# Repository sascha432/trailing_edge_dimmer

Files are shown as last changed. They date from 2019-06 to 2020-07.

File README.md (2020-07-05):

# Trailing Edge MOSFET Dimmer

Firmware for a trailing edge MOSFET dimmer.

* 14bit / 16666 different dimming levels
* Up to 8 different channels
* Store last levels in EEPROM and restore during startup
* EEPROM wear level protection
* Serial protocol to control the dimmer
* I2C or UART interface
* Over temperature protection using an external NTC or the internal ATmega temperature sensor
* Highly configurable to match any hardware

[I2C/UART protocol](https://github.com/sascha432/trailing_edge_dimmer/blob/aabc243a570f12f377fd4b94965764b3ff974f6c/docs/protocol.md)

[Change Log v2.1.4](https://github.com/sascha432/trailing_edge_dimmer/blob/aabc243a570f12f377fd4b94965764b3ff974f6c/CHANGELOG.md)

[Release](https://github.com/sascha432/trailing_edge_dimmer/releases/tag/2.1.4)

## Master Branch

The current master is work in progress and should not be used for any production dimmer.

* Breaking I2C protocol updates
* Cubic interpolation to adjust the brightness curve per channel
* Mains frequency detection between 45 and 65 Hz
* Linear correction removed
* Improved and more precise timings
* Reduced code size by 5-7Kb

[I2C/UART protocol](docs/PROTOCOL.md)

[Change Log v3.0.0](CHANGELOG.md)

## GUI tool for configuration

I created a GUI tool to calibrate, configure and monitor the dimmer via serial port, TCP or web sockets.

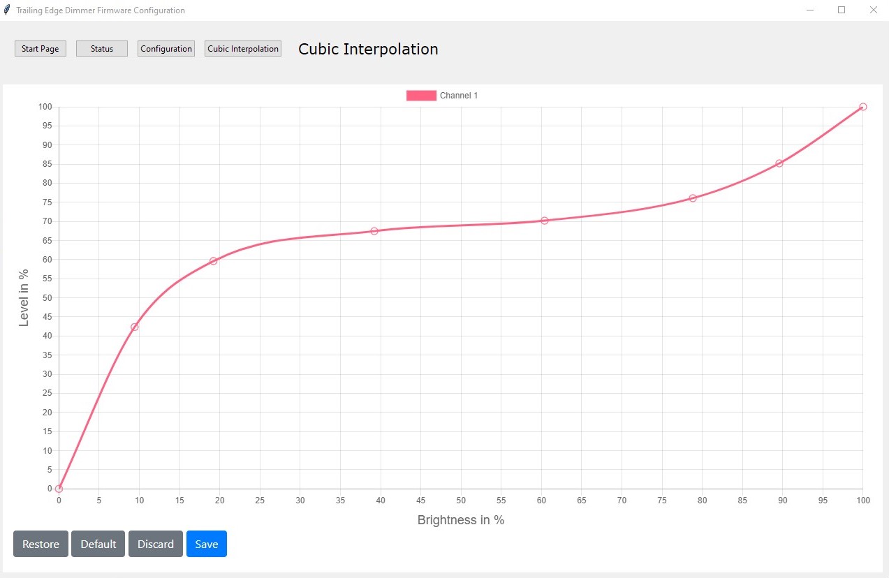
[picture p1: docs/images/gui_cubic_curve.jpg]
GUI tool edit cubic interpolation curve


### Multiple channels

When having multple channels, using a single port reduces any delay when turning channels on. Multiple ports add a slight delay to each channel associated with the port (62.5ns), while version 2 had a delay of 2µs per channel, which added up to 16µs  when having 8 active channels.

Channels that share a port turn on at the same time

* yellow = PORTD
* pink = PORTB
* blue = PORTC

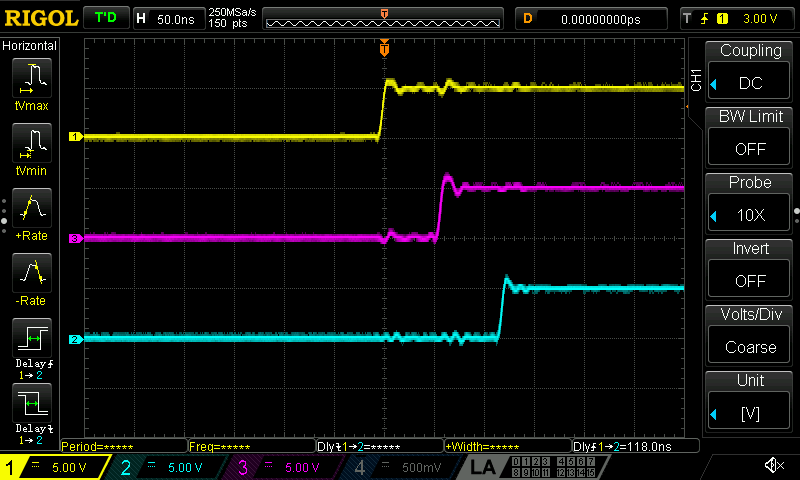
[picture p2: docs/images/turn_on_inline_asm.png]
Version 3


Version 2 or without inline assembler

* yellow = channel#0
* pink = channel#1
* blue = channel#7

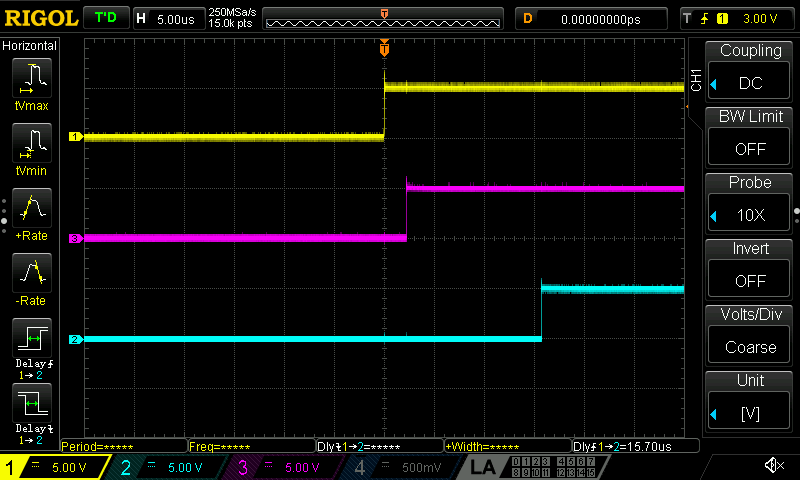
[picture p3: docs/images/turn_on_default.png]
Version 2


## New and improved in-wall dimmer STL files

I have improved and updated the housing for the in-wall dimmer and added print instructions.

* Switches can be mounted on a PCB attached to the plate
* Space for 2 optional LEDs
* Invisible hole for reset switch
* Space for a 20mm fuse holder
* Labels for wires

[3D model in-wall version 1.1](stl/housing/v1.1)

[Instructions](stl/housing/v1.1/README.md)

## New plugin version for 1 Channel Dimmer

Check section [3D models](#3D-models-released) for a plugin housing.

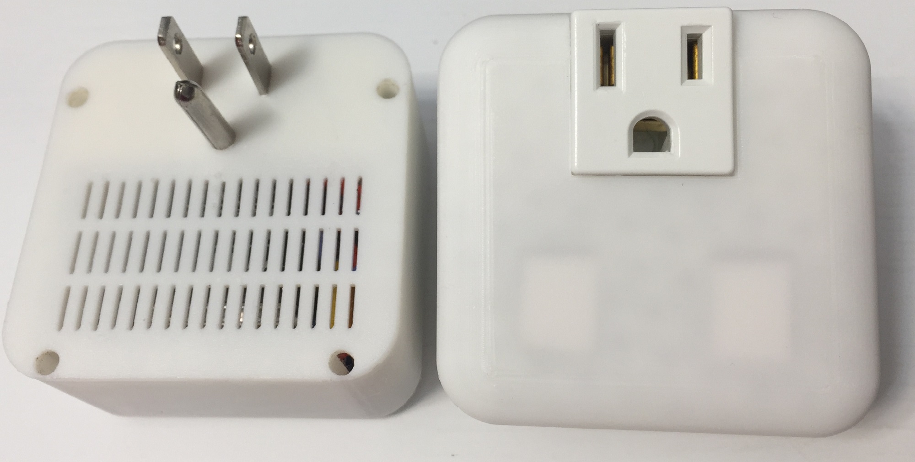
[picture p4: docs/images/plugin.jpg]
Plugin Dimmer


## Updated 4 Channel Dimmer with Power Monitoring

Non isolated version with an offline primary side buck regulator (LNK306), reduced standby consumption of 0.45W compared to 0.58W of the 1 Channel dimmer. Up to 500W with heatsink.

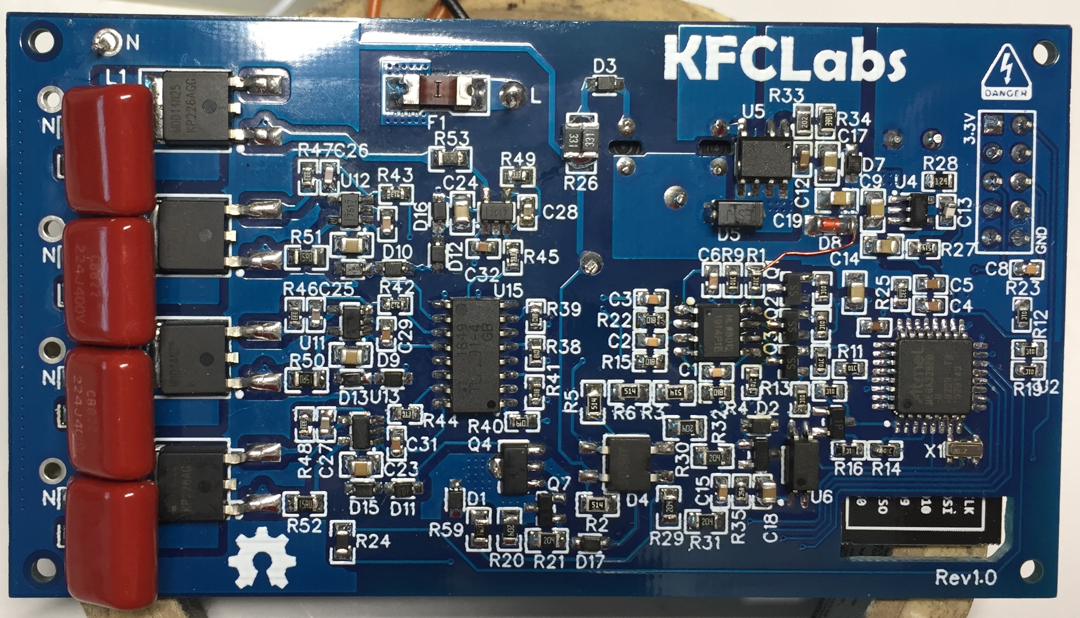
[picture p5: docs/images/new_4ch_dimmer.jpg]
4 Channel Dimmer


[4 Channel Dimmer Schematics and PCB TO-252-2](https://easyeda.com/sascha23095123423/iot-4-channel-dimmer-with-pm)

[4 Channel Dimmer Schematics and PCB TO-220](https://easyeda.com/sascha23095123423/iot-4-channel-dimmer-with-pm_copy)

## Power Monitoring

I've finished testing the new power monitoring feature based on HLW8012 and compatible chips.
The new design uses the Hi-link 3.3V/1A power supply and the MP150, an offline primary side buck regulator, for the non-isolated 5V rail. The regular dimmer got an update as well and 4 MOSFETs can be installed to increase the maximum power up to 200/400W.

[1 Channel Dimmer with Power Monitor](https://easyeda.com/sascha23095123423/iot_1ch_dimmer_copy_copy_copy)

[1 Channel Dimmer with 4 MOSFETs](https://easyeda.com/sascha23095123423/iot_1ch_dimmer_copy_copy_copy_copy)

[New WiFi control board](https://easyeda.com/sascha23095123423/esp12e_iot_module_copy)

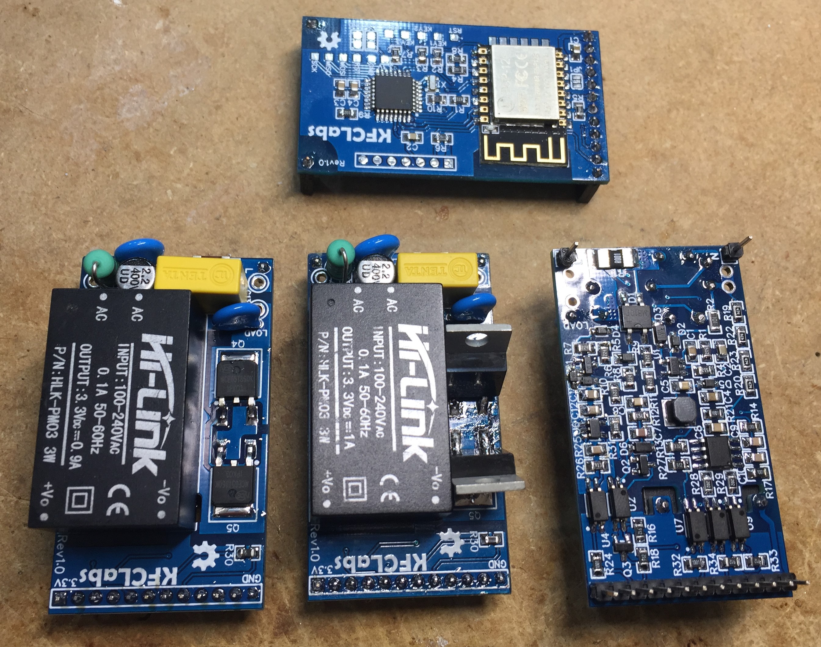
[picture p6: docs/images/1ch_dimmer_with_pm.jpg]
New PCBs


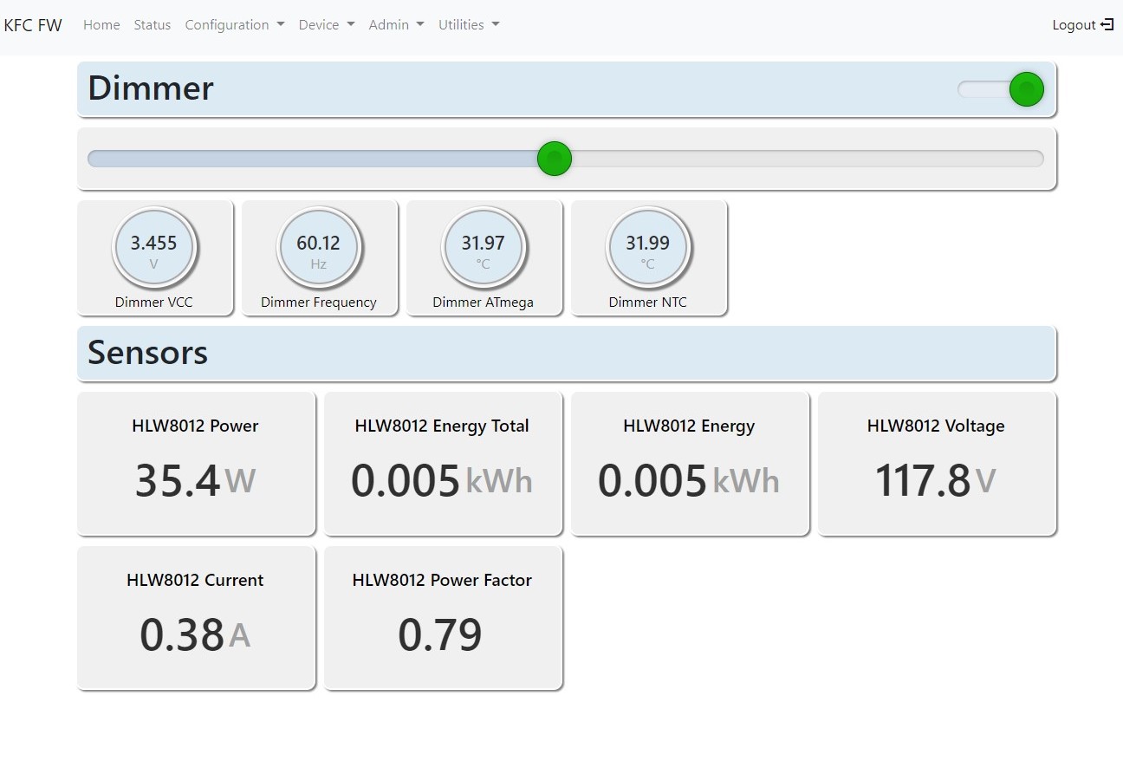
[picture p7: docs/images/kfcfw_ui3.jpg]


## WiFi Firmware update

The recent version of the KFC firmware supports programming the ATmega over the STK500v1 protocol directly from the ESP8266. I am using the Arduino bootloader for the ATmega328P mini PRO board@8MHz (ATmegaBOOT_168_atmega328_pro_8MHz.hex)

[KFC Firmware @ Github](https://github.com/sascha432/esp8266-kfc-fw)

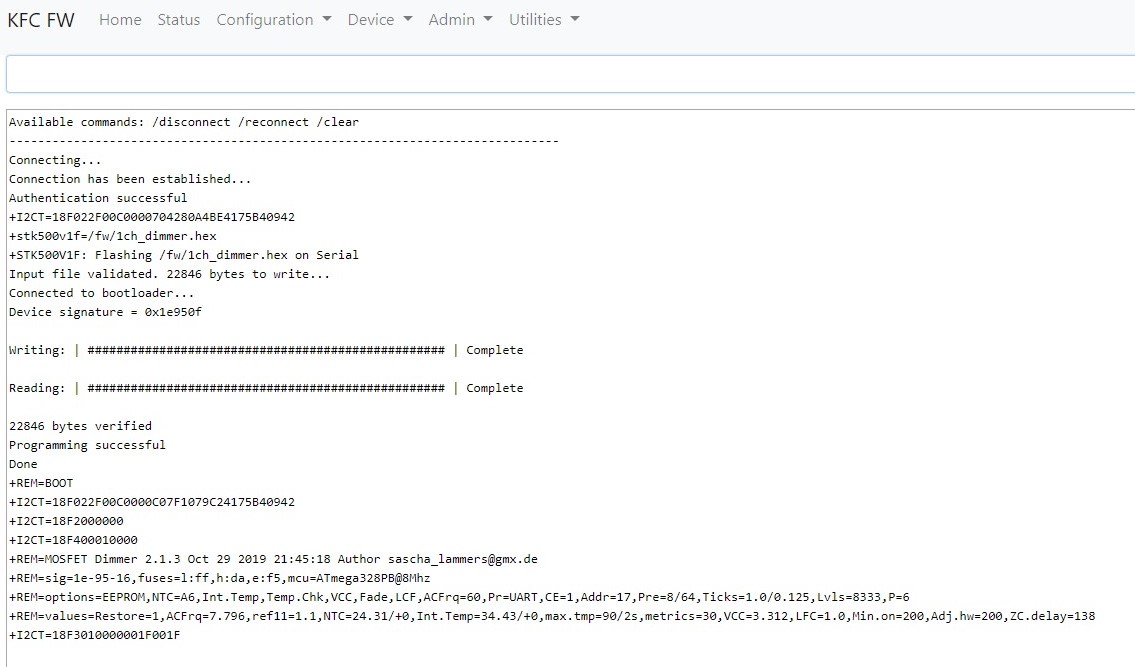
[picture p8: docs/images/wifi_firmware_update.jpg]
WiFi Firmware Update


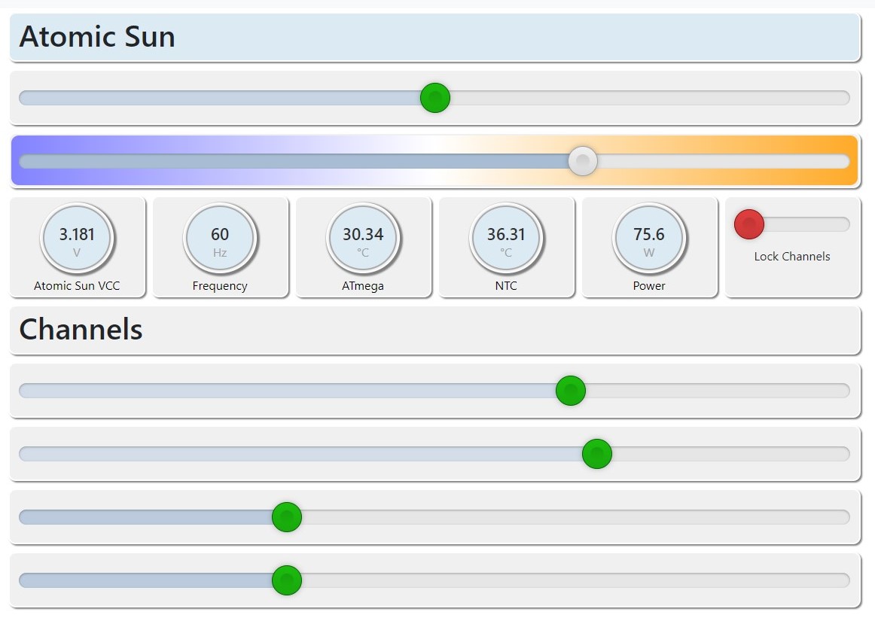
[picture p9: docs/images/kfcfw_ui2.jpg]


## Zero crossing detection update

I've improved the zero crossing detection by adding a RC filter, which improves the signal but still has a 0.5% error rate compared to 2.2% before.
Software filtering reduces the error rate to 0.001% even without the RC filter.

Test environment: 4x10W LED + 60W incandescent bulb, 50% dimmed, random 1000-2500V transients 5-20µs several times per second on the AC side.

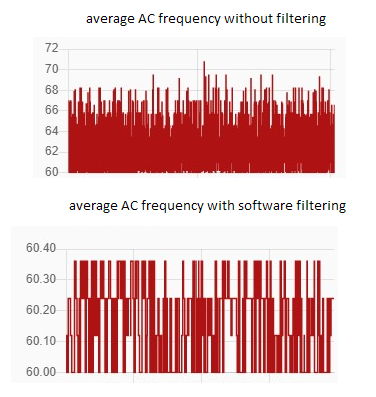
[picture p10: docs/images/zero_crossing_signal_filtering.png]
Comparision of unfiltered and filtered signal


## 3D models released

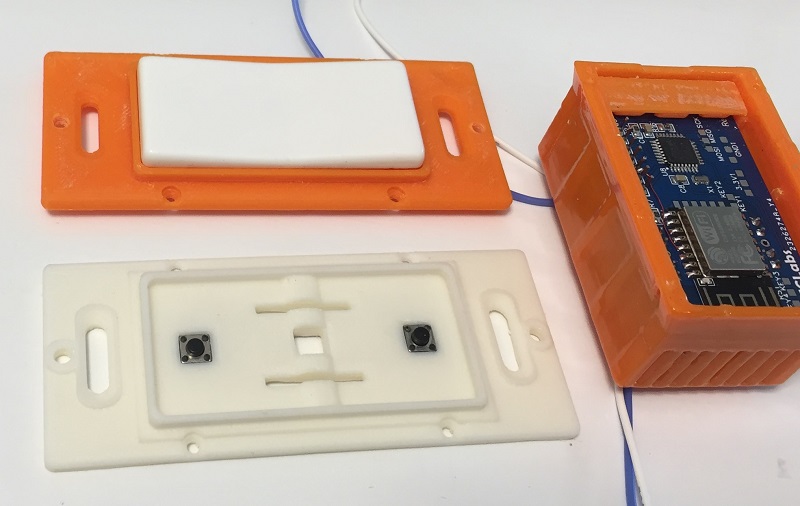
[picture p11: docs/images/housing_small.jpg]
Printed version


[Open image](https://raw.githubusercontent.com/sascha432/trailing_edge_dimmer/master/docs/images/housing.jpg)

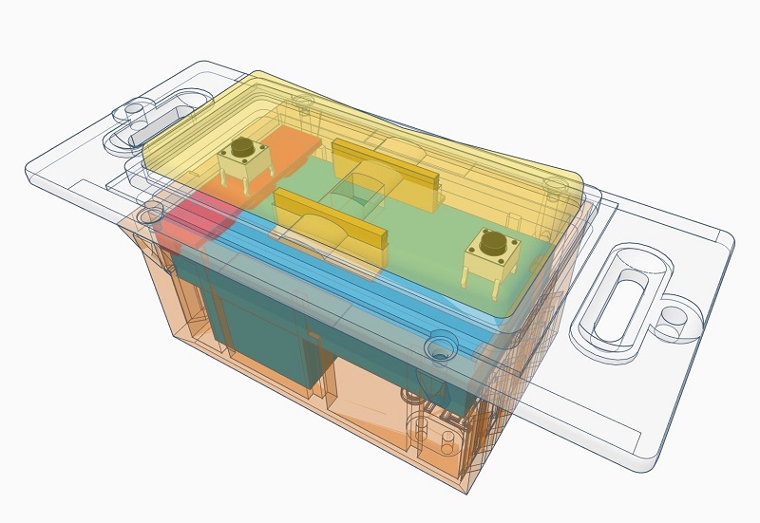
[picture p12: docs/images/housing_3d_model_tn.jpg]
3D model


[Open image](https://raw.githubusercontent.com/sascha432/trailing_edge_dimmer/master/docs/images/housing_3d_model.jpg)

[3D model in-wall version](stl/housing)

[3D model plugin version](stl/housing/plugin)

## Tested PCB Rev 3.3 is online

* [4 Channel Dimmer](https://easyeda.com/sascha23095123423/trailing-edge-dimmer-rev2)

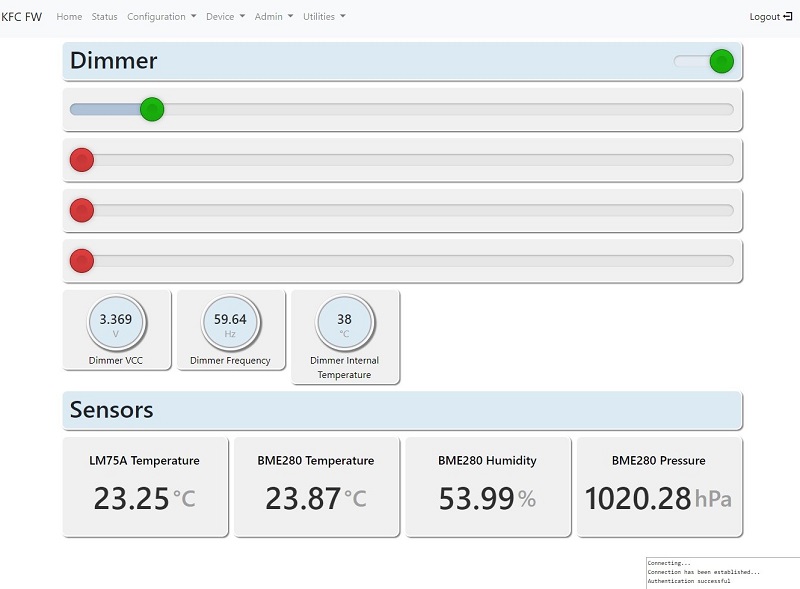
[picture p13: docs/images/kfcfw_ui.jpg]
KFC FW UI

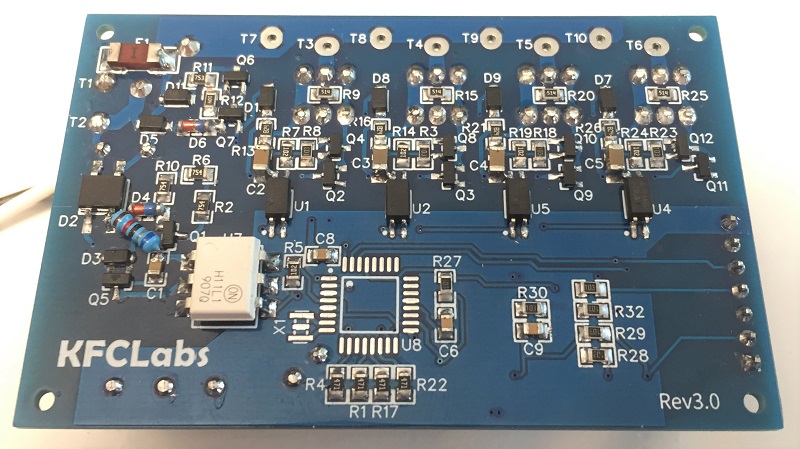
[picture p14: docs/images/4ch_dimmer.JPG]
4 Channel Dimmer


## PCBs arrived and first prototype is working

* In-Wall Dimmer
* ESP8266 with MQTT and Home Assistant integration
* Atmega328P as controller over UART
* [ESP12E/Atmega328P Control Module](https://easyeda.com/sascha23095123423/esp12e_iot_module)
* [1 Channel Dimmer Module](https://easyeda.com/sascha23095123423/iot_1ch_dimmer)

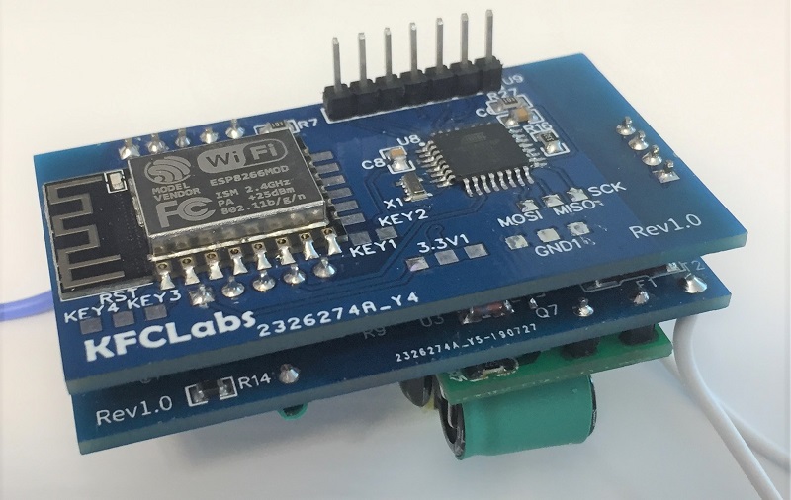
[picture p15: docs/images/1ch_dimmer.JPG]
1 Channel Dimmer


Testing it with a PWM generator to simulate the zero crossing signal, dimming a LED instead switching the MOSFET. The 120V part is waiting for opto couplers.

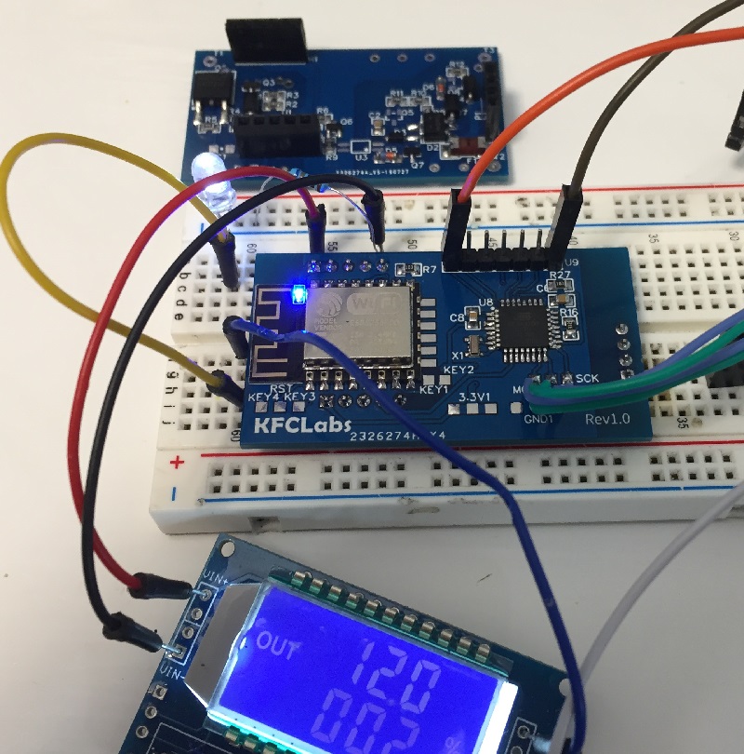
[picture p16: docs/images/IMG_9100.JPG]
Testing PCB


## Schematics of the final design

* 3.3V only
* Improved power consumption (~0.3-0.4W idle depending on the power supply)
* Improved MOSFET switching

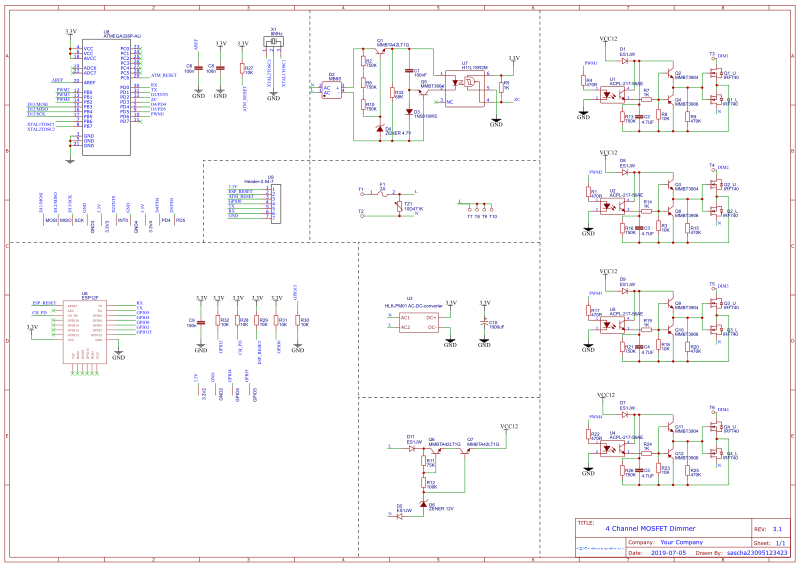
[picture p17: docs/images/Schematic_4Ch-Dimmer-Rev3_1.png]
Final design


[Open schematics...](https://easyeda.com/sascha23095123423/trailing-edge-dimmer-rev2)

## Improved zero crossing detection

* Low current consumption (0.15mA @ 120V)
* Tested with 85-265V 50/60Hz
* Logic level output with different opto isolators (4N25, PC817, ACPL-217)
* 50-110us pulse width to extend opto isolator live

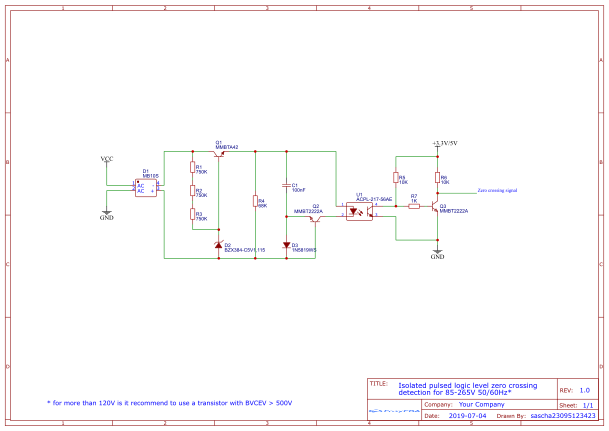
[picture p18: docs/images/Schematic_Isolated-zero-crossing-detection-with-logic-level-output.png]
Zero crossing detection


[Open schematics...](https://easyeda.com/sascha23095123423/isolated-zero-crossing-detection-with-logic-level-output)

## In action

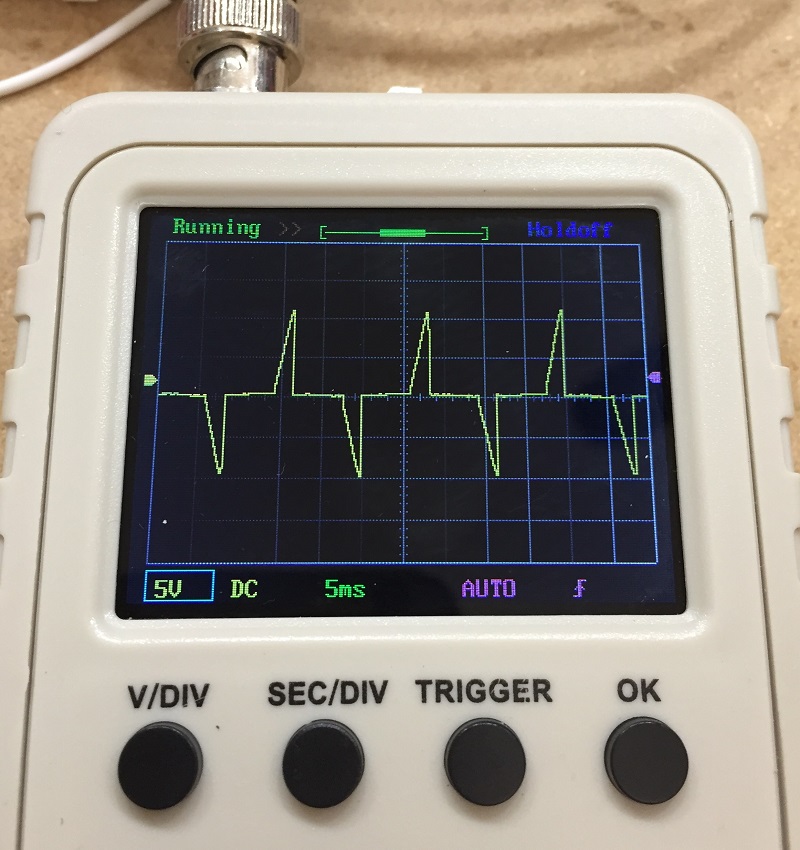
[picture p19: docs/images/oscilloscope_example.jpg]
In action


## Dev board schematics with ESP8266

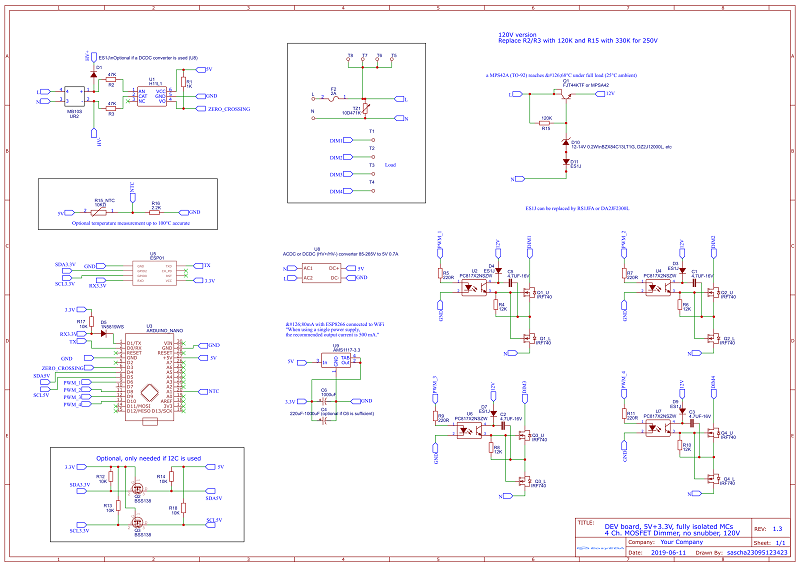
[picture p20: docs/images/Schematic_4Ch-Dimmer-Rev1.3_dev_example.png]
Dev board


[Open schematics...](https://github.com/sascha432/trailing_edge_dimmer/blob/master/docs/schematics/Schematic_4Ch-Dimmer-Rev1.3_dev_example.svg)

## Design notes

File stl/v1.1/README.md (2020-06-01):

# Print Settings

***NOTE*** **WORK IN PROGRESS, STL FILES MIGHT CHANGE AND FILES ARE MISSING**

Print settings are for CURA 4.x and tested with a CR10S PRO

Temperature settings depend on your PLA/ABS/PETG and build surface.

## Safety and fire hazards

***If mains voltage or high currents are involved, make sure everything is adequately protected.***

**It is highly recommended to use Flame Retardant ABS or Polycarbonate Filament for any parts that involve electricity.**

ABS that is exposed to high temperatures (>60°C) has the tendency to become very brittle over time. Keep that in mind for areas important for structural integrity. Adding slots for inserting pieces of aluminium is a good option.

### Further protection of plastic against heat

A layer of aluminium tape and Kapton on top protects plastic pretty well for a short period of time, even if a gas torch is used trying to light it up. Areas around fuses that are prone to high heat and burning plasma when they blow, can be protected this way. Do not use glas fuses, but sand filled/ceramic ones that do not explode and proper ceramic fuse holders. Areas where cables are connected (screw/crimp terminals etc...) should be protected this way too.

### Parts

### Housing

- Use flame retardant ABS or polycarbonate
- Custom support required
- The screw holes for the plate are 5mm/0.8mm, then 5mm/2.6mm. Use a drill (max. 10mm depth) to adjust it and use a thread cutter if desired.

## Plate

- Use flame retardant ABS/PC with high infill
- No support required

## Rocker switch

- Can be PLA or PETG, my favorite is PETG
- No support required
- The angled switch consists of two parts that need to be glued together (cyanoacrylate) to get a perfect smooth surface
- The clip that holds the switch in the plate should be printed with PETG or ABS

## Warping

Warping is usually the result of an incorrect z-height, dirty surface, flow rate, wrong temperature (bed, nozzle, environment), fan speed/fan duct or draft.

- Wash your PEI sheet with dishwashing detergent, rinse with plenty of hot water and use gloves. Repeat the process a couple times. Isopropyl alcohol can be used to remove minor dirt, but grease/dust is usually spread around if not rinsed well
- Clean glas or Kapton with acetone
- Adjust your z-height while printing by adding a couple more lines of skirt/brim
- For ABS: Increasing or decreasing the amount of infill can prevent warping. If your slicer supports different infill, use 65-80% infill for the first 10mm height to prevent uneven expansion during cooling
- If warping occurs on one side, the direction of the fan duct might be the reason
- Make it stick with ABS juice (works for ABS and PLA), glue stick, hair spray or if nothing helps, use a raft

## Support

- Support density 15-20%
- Support floor/roof interface 0.64mm (4 layers), density 20-35%
- Placement everywhere
- Z-distance 0.16mm
- If the support cannot be removed, use fan override, increase Z-distance and check if the flow rate is too high
- **For ABS**: Fan override off, if it causes warping
- Make sure to disable "Generate Support" after changing settings

## Using custom support

- Load both files into CURA
- Select the support and change per model settings to "print as support"
- Select both models (Ctrl+A = select all) and right click, merge models (or Ctrl+Alt+G)
- Verify that the support and model position match and z-height is 0mm
- Disable "Generate Support"

## Shell/Infill

- Layer height 0.16mm
- Wall 1.2mm
- Top/Bottom 1.2mm
- Horizontal expansion and hole horizontal expansion *-0.16mm*. Make sure to run a test print if holes and dimensions are correct
- Housing (ABS): 20-30% infill, cubic or gyroid
- Plate and rocker switch: 75-85% infill, lines
- Speed 50mm, 15mm for intial layer

## PLA

Settings for a PEI flex sheet.

- Skirt 2-3 lines to clean the nozzle
- Nozzle 195-200°C
- Bed temperature intial layers (2-3) 75°C, then 60°C
- Retraction 5mm, speed 45mm
- Fan speed 100%
- Bridge settings can be enabled

Some PLA does not stick well and tends to warp. I am using a raft with 10mm margin for those cases or print on glas/Kapton with ABS juice.

## ABS

Settings for a flex steel sheet with Kapton tape. Glas works very well too, but it is hard to remove the bigger the surface. Aluminium works to a certain degree if the surface is rough enough (wet sanding paper, grit ~400).

If the Kapton tape does not stick, make sure to wash your plate with dishwashing detergent, rinse with plenty of hot water and clean it with acetone before applying the tape. Heat it up to 120°C and use a lot pressure to make it stick very well. If air bubbles cannot the removed, use a needle to pinch tiny holes into the tape. **Repeat the process** of heating it up and appling pressure to the area where the model has been removed.

- Use ABS juice to make it stick. It can be highly diluted with acetone
- Make sure the fan is off at all times, no bridge settings
- Brim 10mm or 10 lines of skirt, distance 1mm, draft shield 1mm, height 5mm. That prevents warping very well
- Nozzle 220-235°C
- Bed temperature 85-90°C
- Retraction 5mm, speed 50mm
- Heated chamber 40°C

## PETG

Settings for a PEI flex sheet.

- Nozzle 220°C
- Bed temperature 75°C
- Retraction 6.8mm, speed 80mm
- Brim 10mm or a raft with 10mm, if warping occurs
- Fan speed 50%
- Bridge settings can be enabled

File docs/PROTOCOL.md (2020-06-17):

# I2C/UART protocol

The dimmer is controlled via I2C or UART interface.

The default address is 0x17 (referred to as ADDRESS) for the slave. When sending data, the dimmer acts as master and sends to address 0x18 (slave address + 1, refred to as MASTER_ADDRESS).

The values for the registers and commands can be found in [dimmer_protocol.h](../src/dimmer_protocol.h)

The examples are using the UART protocol and can send to the dimmer using any terminal software.

Using the Arduino TwoWire class (or the drop-in replacement for UART [SerialTwoWire](https://github.com/sascha432/i2c_uart_bridge)) instead:

    // to slave +I2CT=ADDRESS,REGISTER_COMMAND,COMMAND_READ_VCC (+I2CT=17,0A,22)
    Wire.beginTransmission(DIMMER_I2C_ADDRESS);
    Wire.write(DIMMER_REGISTER_COMMAND);
    Wire.write(DIMMER_COMMAND_READ_VCC);
    if (Wire.endTransmission() == 0) {

        // to slave +I2CR=ADDRESS,02 (+I2CR=17,02)
        uint16_t vcc;
        if (Wire.requestFrom(DIMMER_I2C_ADDRESS, sizeof(vcc)) == sizeof(vcc)) {         // from slave: +I2CT=ADDRESS,CD,12 (+I2CT=17,CD,12)
            Wire.readBytes(reinterpret_cast<const uint8_t *>(&vcc), sizeof(vcc));       // vcc = 0x12CD/4813 (4.813V)
        }
    }

## Translating commands

Writing HEX commands is cumbersome. There is a python script that can translate constants into HEX commands. It can process single commands or an entire file.

`scripts/trans_cmd.py`

Supported values are:

- ADDRESS
- MASTER_ADDRESS
- Name of the constant (DIMMER_REGISTER_FROM_LEVEL, DIMMER_COMMAND_READ_VCC, ...)
- Short version of the constant (REGISTER_FROM_LEVEL, COMMAND_READ_VCC)
- int8 (ff or b-1)
- uint8 (ff or b255)
- int16 (ffff or w-1)
- uint16 (ffff or w65535)
- Float (ffffffff or 100.5)
- Hex uint32 (eeeeeeee or q4008636142)

```
# trans_cmd.py command "I2CT=ADDRESS,COMMAND_READ_VCC,DIMMER_REGISTER_FROM_LEVEL,1f,2faa,100.5,4a3b2c1d,b-1,w1000,w-1"
+I2CT=17,22,01,1F,2F,AA,42,c9,00,00,4A,3B,2C,1D,FF,03,E8,FF,FF
```

## DIMMER_COMMAND_FADE

The fading command uses following registers

- DIMMER_REGISTER_FROM_LEVEL (int16, little endian)
- DIMMER_REGISTER_CHANNEL (int8)
- DIMMER_REGISTER_TO_LEVEL (int16)
- DIMMER_REGISTER_TIME (float, 32bit, little endian)

The fade command can be sent in a single write operation.

### From level

If set to -1 / 0xffff, it will start with the current level set. The default value is -1.

### Channel

Channels are 0 based and -1 / 0xff means all channels

### Examples

Set **from level** to current level -1, **channel** to 0, **to level** to 2250, **time** 7.5 (seconds) and execute fade command

    +I2CT=ADDRESS,REGISTER_FROM_LEVEL,w-1,00,w2250,7.5,COMMAND_FADE (+I2CT=17,01,FF,FF,00,CA,08,00,00,F0,40,11)

Set **channel** to all channels (0xff = -1), **to level** to 1533, **time** 7.5 and execute fade

    +I2CT=ADDRESS,REGISTER_CHANNEL,b-1,w1533,7.5,COMMAND_FADE (+I2CT=17,03,FF,FD,05,00,00,F0,40,11)

## DIMMER_COMMAND_SET_LEVEL

The fading command uses following registers

- DIMMER_REGISTER_CHANNEL (int8)
- DIMMER_REGISTER_TO_LEVEL (int16)

Set **channel** to 1, **to level** to 777 and execute set level command

    +I2CT=ADDRESS,REGISTER_CHANNEL,01,w777 (+I2CT=17,03,01,09,03)
    +I2CT=ADDRESS,REGISTER_COMMAND,COMMAND_SET_LEVEL (+I2CT=17,0A,10)

To send the command in one transmission, the time can be filled with any data

    +I2CT=ADDRESS,REGISTER_CHANNEL,01,w777,0.0,COMMAND_SET_LEVEL (+I2CT=17,03,01,09,03,00,00,00,00,10)

## DIMMER_COMMAND_READ_xxx

This applies to

- DIMMER_COMMAND_READ_NTC (float)
- DIMMER_COMMAND_READ_INT_TEMP (float)
- DIMMER_COMMAND_READ_VCC (uint16)

If no further data is sent after the read command, the register is set automatically to

- DIMMER_REGISTER_TEMP (float)
- DIMMER_REGISTER_INT_TEMP (float)
- DIMMER_REGISTER_VCC (uint16)

**NOTE:** Reading VCC and temperature takes ~50ms. The +I2CR command must be delayed that long.

Read VCC

    +I2CT=ADDRESS,REGISTER_COMMAND,COMMAND_READ_VCC (+I2CT=17,0A,22)
    ...wait 50ms
    +I2CR=ADDRESS,02 (+I2CR=17,02)

Response ("\x21\x13" = 0x1321 = 4.897V)

    +I2CT=ADDRESS,21,13 (+I2CT=17,21,13)

Read internal temperature

    +I2CT=ADDRESS,REGISTER_COMMAND,COMMAND_READ_INT_TEMP (+I2CT=17,0A,21)
    ...wait 50ms
    +I2CR=ADDRESS,04 (+I2CR=17,04)

Response ("\x55\x5C\x86\x41" = 16.795°C)

    +I2CT=ADDRESS,55,5C,86,41 (+I2CT=17,55,5C,86,41)

Read AC frequency

    +I2CT=ADDRESS,REGISTER_COMMAND,23 (+I2CT=17,0A,23)
    +I2CR=ADDRESS,04 (+I2CR=17,04)

## DIMMER_COMMAND_READ_CHANNELS

Read one or more channel

- DIMMER_REGISTER_CH0_LEVEL (int16)
- DIMMER_REGISTER_CH1_LEVEL
- DIMMER_REGISTER_CH2_LEVEL
- DIMMER_REGISTER_CH3_LEVEL
- DIMMER_REGISTER_CH4_LEVEL
- DIMMER_REGISTER_CH5_LEVEL
- DIMMER_REGISTER_CH6_LEVEL
- DIMMER_REGISTER_CH7_LEVEL

The byte after command specifies the number of channels and start address, each 4 bit. If omitted, all 8 channels are read.

Channel 1 - 4 (0x40)

    +I2CT=ADDRESS,REGISTER_COMMAND,COMMAND_READ_CHANNELS,40 (+I2CT=17,0A,12,40)
    +I2CR=ADDRESS,08 (+I2CR=17,08)

Channel 8 (0x17)

    +I2CT=ADDRESS,REGISTER_COMMAND,COMMAND_READ_CHANNELS,17 (+I2CT=17,0A,12,17)
    +I2CR=ADDRESS,02 (+I2CR=17,02)

Channel 2 and 3 (0x21)

    +I2CT=ADDRESS,REGISTER_COMMAND,COMMAND_READ_CHANNELS,21 (+I2CT=17,0A,12,21)
    +I2CR=ADDRESS,04 (+I2CR=17,04)

## DIMMER_COMMAND_WRITE_EEPROM

Store configuration and current levels in EEPROM

    +I2CT=ADDRESS,REGISTER_COMMAND,COMMAND_WRITE_EEPROM (+I2CT=17,0A,50)

## DIMMER_COMMAND_RESTORE_FS

Restore factory settings and re-initialize EEPROM wear leveling

    +I2CT=ADDRESS,REGISTER_COMMAND,COMMAND_RESTORE_FS (+I2CT=17,0A,51)

## DIMMER_COMMAND_READ_TIMINGS

Read timings for fine tuning. The return type is float and all values are in micro seconds

- DIMMER_TIMINGS_TMR1_TICKS_PER_US
- DIMMER_TIMINGS_TMR2_TICKS_PER_US
- DIMMER_TIMINGS_ZC_DELAY_IN_US
- DIMMER_TIMINGS_MIN_ON_TIME_IN_US
- DIMMER_TIMINGS_ADJ_HW_TIME_IN_US

Read zero crossing delay

    +I2CT=ADDRESS,REGISTER_COMMAND,REGISTER_CONFIG_OFS,TIMINGS_ZC_DELAY_IN_US (+I2CT=17,0A,23,03)
    +I2CR=ADDRESS,04 (+I2CR=17,04)

**NOTE:** Values are stored in ticks in the EEPROM. DIMMER_TIMINGS_TMR1_TICKS_PER_US and DIMMER_TIMINGS_TMR2_TICKS_PER_US can be used to translate time to ticks.

## Reading and writing the dimmer settings

- DIMMER_REGISTER_OPTIONS (uint8)
- DIMMER_REGISTER_MAX_TEMP (uint8, °C)
- DIMMER_REGISTER_FADE_IN_TIME (float, seconds)
- DIMMER_REGISTER_TEMP_CHECK_INT (uint8, seconds)
- DIMMER_REGISTER_LC_FACTOR (float)
- DIMMER_REGISTER_ZC_DELAY_TICKS (uint8)
- DIMMER_REGISTER_MIN_ON_TIME_TICKS (uint16)
- DIMMER_REGISTER_ADJ_HALFWAVE_TICKS (uint16)

### Options

- Bit 0: Restore last levels on power up
- Bit 1: Report temperature and over-temperature alarm (UART only)
- Bit 2: Temperature alarm indication. Needs to be cleared manually

To make any changes permanent, **DIMMER_COMMAND_WRITE_EEPROM** needs to be executed.

Read all settings

length is sizeof(register_mem_cfg_t), 0x10 in this example

    +I2CT=ADDRESS,REGISTER_READ_LENGTH,10,REGISTER_OPTIONS (+I2CT=17,0B,10,23)
    +I2CR=ADDRESS,10 (+I2CR=17,10)

Read temperature check interval

    +I2CT=ADDRESS,REGISTER_READ_LENGTH,REGISTER_START_ADDR,REGISTER_TEMP_CHECK_INT (+I2CT=17,0B,01,29)
    +I2CR=ADDRESS,01 (+I2CR=17,01)

Response (0x02, 2 seconds)

    +I2CT=ADDRESS,02 (+I2CT=17,02)

Set temperature check interval/metrics reporting to 30 seconds

    +I2CT=ADDRESS,REGISTER_TEMP_CHECK_INT,b30 (+I2CT=17,29,1E)

**NOTE:** The interval changes after the next check. DIMMER_COMMAND_FORCE_TEMP_CHECK (*+I2CT=ADDRESS,REGISTER_COMMAND,COMMAND_FORCE_TEMP_CHECK (+I2CT=17,0A,54)*) can be used to force a check without waiting

## DIMMER_COMMAND_PRINT_INFO

Print dimmer info on serial port

    +I2CT=ADDRESS,REGISTER_COMMAND,COMMAND_PRINT_INFO (+I2CT=17,0A,53)

Response

Signature, compile options, current values and errors are returned

    +REM=sig=1e-95-0f,fuses=l:ff,h:da,e:fd,MCU=ATmega328P@16Mhz
    +REM=options=EEPROMwr=0,NTC=A0,IntTemp,TempChk,VCC,Fade,ACFrq=60,Pr=UART,CE=1,Addr=17,Pre=8/128,Ticks=2.0/0.125us,MaxLvls=16666,GPIO/lvl=6/0,8/0,9/0,10/0
    +REM=values=Restore=1,MainsFrq=60.24,Ref11=1.1,NTC=24.19/+0.0C,IntTemp=16.80/-10.0C,MaxTmp=65/2s,MetricsInt=30s,VCC=4.876,MinOn=240/120.00us,AdjHW=400/200.00us,ZCDelay=10/80.00us
    +REM=errors=FrqHi/Low=0/0,ZCmisfire=0,EEPROMCrcErr=1

## DIMMER_COMMAND_ZC_TIMINGS_OUTPUT

If ZC_MAX_TIMINGS is enabled, the dimmer outputs the zero crossing timings to the serial console every ZC_MAX_TIMINGS_INTERVAL milliseconds. ZC_MAX_TIMINGS needs to be equal or higher than the amount of expected data within this period. Collecting the data does not cause a delay of the ZC interrupt.

The data expected is a boolean. Non-zero values enable the output on.

    +I2CT=ADDRESS,REGISTER_COMMAND,COMMAND_ZC_TIMINGS_OUTPUT,01 (+I2CT=17,0A,60,01)

### Outut format

The first argument is the return value of micros() (uint32) hex encoded. Every following the difference to the previous time (uint16)

+REM=ZC,\<microseconds\> [\<delay\> [\<delay\> ...]]

    +REM=ZC,17f8c010 20b8 20b4 20b4 20b8 20b4 20b8 ...

## DIMMER_COMMAND_PRINT_METRICS

Print metrics every 5 seconds on serial port in human readable form. The following byte enables (non 0) or disables the output

    +I2CT=ADDRESS,REGISTER_COMMAND,COMMAND_PRINT_METRICS,05 (+I2CT=17,0A,55,05)

## DIMMER_COMMAND_PRINT_CUBIC_INT

Prints the cubic interpolation tables to the serial port. The first byte is the channel, -1 for all

    +I2CT=ADDRESS,REGISTER_COMMAND,COMMAND_PRINT_CUBIC_INT,b-1 (+I2CT=17,0A,56,FF)

Format:

Channel, X values, Y values, interpolated values per level

    +REM=ch=<num>,x=[0,1,...],y=[0,1,...],l=[0,1,7,20,300,...]

## DIMMER_COMMAND_GET_CUBIC_INT

Translate up to 11 levels for the provided table at once. This can be used to retrieve a preview of the entire curve. The returned values are int16

Table format:

`<level:int16>,<number of levels:uint8>,<x1:uint8>,<x2>,...,<y1:int16>,<y2>,...`

    +I2CT=ADDRESS,REGISTER_COMMAND,DIMMER_COMMAND_GET_CUBIC_INT,w10,b11,00,02,07,w0,w2500,w8192 (+I2CT=17,0A,57,0A,00,0B,00,02,07,00,00,C4,09,00,20)
    +I2CR=ADDRESS,b22 (+I2CR=17,16)

## DIMMER_COMMAND_FORCE_TEMP_CHECK

Force temperature check and report metrics if enabled

    +I2CT=ADDRESS,REGISTER_COMMAND,COMMAND_FORCE_TEMP_CHECK (+I2CT=17,0A,54)

## DIMMER_COMMAND_DUMP_MEM

Dump the content of the register memory to the serial port

    +I2CT=ADDRESS,REGISTER_COMMAND,COMMAND_DUMP_MEM (+I2CT=17,0A,EE)

## DIMMER_COMMAND_DUMP_CFG

Print the entire configration on the serial port as backup

    +I2CT=ADDRESS,REGISTER_COMMAND,COMMAND_DUMP_CFG (+I2CT=17,0A,91)

## DIMMER_COMMAND_SIMULATE_ZC

Simulate zero crossing events for 8 seconds. This will cause misfire if DIMMER_SIMULATE_ZC is not set

    +I2CT=ADDRESS,REGISTER_COMMAND,COMMAND_SIMULATE_ZC,08 (+I2CT=17,0A,E0,08)

## Temperature, VCC status and AC Frequency (DIMMER_RESPONSE_METRICS_REPORT)

If metrics reporting is enabled, the dimmer sends dimmer_metrics_t with DIMMER_TEMPERATURE_REPORT to it's own I2C address + 1.
This can also be trigger with the command DIMMER_COMMAND_FORCE_TEMP_CHECK. The maximum interval is set with cfg.report_metrics_max_interval, the minimum is cfg.temp_check_interval. The event is sent either when the maximum time has been reached, or if any values has changed significantly.

If data is not available, 0 (for VCC) or NaN (for any float) is returned.

    +I2CT=MASTER_ADDRESS,RESPONSE_METRICS_REPORT,02,... (+I2CT=18,F0,02)

## Temperature Alarm (DIMMER_RESPONSE_TEMPERATURE_ALERT)

If the max. temperature was exceeded, it sends one alarm with register address DIMMER_RESPONSE_TEMPERATURE_ALERT, the current temperature (uint8) and the temperature threshold (uint8)

Current temperature 37°C, threshold 85°C

    +I2CT=MASTER_ADDRESS,RESPONSE_TEMPERATURE_ALERT,25,55 (+I2CT=18,F1,25,55)

## Fading completed (DIMMER_RESPONSE_FADING_COMPLETE)

When fading to a new level has been completed, the dimmer sends DIMMER_RESPONSE_FADING_COMPLETE, with channel (int8) and level (int16). Channel and level can occur multiple times in the case 2 channels finished at the same time.

Channel 0 and 1 reached 0x1234 and fading is complete:

    +I2CT=MASTER_ADDRESS,RESPONSE_FADING_COMPLETE,00,12,34,01,12,34 (+I2CT=18,F2,00,12,34,01,12,34)

Channel 0 reached level 0:

    +I2CT=MASTER_ADDRESS,RESPONSE_FADING_COMPLETE,00,00,00 (+I2CT=18,F2,00,00,00)

## EEPROM written event (DIMMER_RESPONSE_EEPROM_WRITTEN)

EEPROM writes might be delayed due to wear leveling. Once written, DIMMER_RESPONSE_EEPROM_WRITTEN with structure DIMMER_RESPONSE_EEPROM_WRITTEN_t is sent.

    +I2CT=MASTER_ADDRESS,RESPONSE_EEPROM_WRITTEN,01,00,00,00,21,00,DC (+I2CT=18,F3,01,00,00,00,21,00,DC)

## Frequency warning (DIMMER_RESPONSE_FREQUENCY_WARNING)

If a too low or high frequency (<75% >120%) is detected, DIMMER_RESPONSE_FREQUENCY_WARNING will be sent. The second byte indicates if it was too low (0) or high (1), followed by register_mem_errors_t.
No zero crossing signal does not fire this event, but the frequency measurement will return NaN.

The errors are stored in *cfg.bits.frequency_low* and *cfg.bits.frequency_high*, which need to be reset manually.

## Zero Crossing calibration

Following commands are available for calibration.

Increase zero crossing delay by 1 tick

    +I2CT=ADDRESS,REGISTER_COMMAND,COMMAND_ZC_INCREASE (+I2CT=17,0A,83)

Decrease zero crossing delay

    +I2CT=ADDRESS,REGISTER_COMMAND,COMMAND_ZC_DECREASE (+I2CT=17,0A,82)

Set zero crossing delay to -31 ticks or -15.5µs and print setting

    +I2CT=ADDRESS,REGISTER_COMMAND,COMMAND_SET_ZC,w-31 (+I2CT=17,0A,92,E1,FF)
    +I2CT=ADDRESS,REGISTER_COMMAND,COMMAND_SET_ZC,-15.5 (+I2CT=17,0A,92,00,00,78,C1)

The settings need to be stored in the EEPROM. The following command forces to write the EEPROM

    +I2CT=ADDRESS,REGISTER_COMMAND,COMMAND_FORCE_WRITE_EEPROM (+I2CT=17,0A,93)

Restore factory settings

    +I2CT=ADDRESS,REGISTER_COMMAND,COMMAND_RESTORE_FS (+I2CT=17,0A,51)

Display dimmer info

    +I2CT=ADDRESS,REGISTER_COMMAND,COMMAND_PRINT_INFO (+I2CT=17,0A,53)

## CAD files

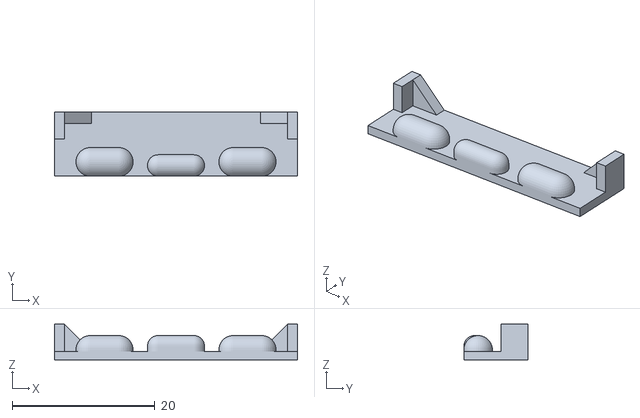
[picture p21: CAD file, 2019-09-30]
stl/housing/insulation-spacer.stl
34.0 x 9.00 x 5.00

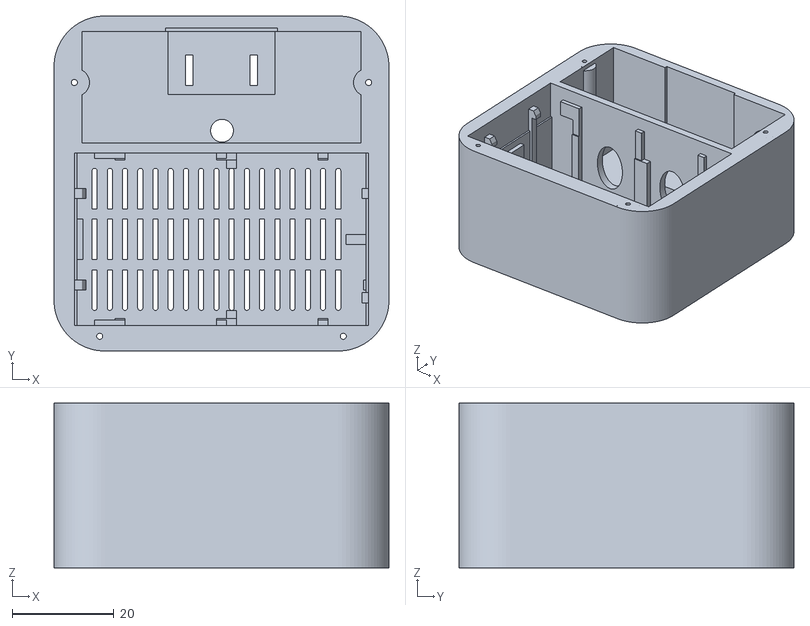
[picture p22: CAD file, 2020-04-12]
stl/housing/plugin/housing.stl
66.0 x 66.0 x 32.5

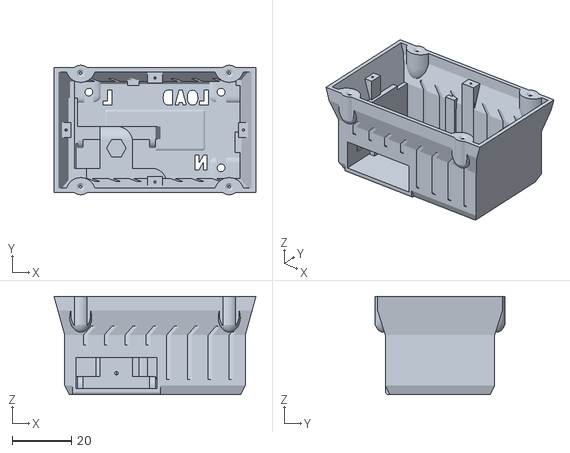
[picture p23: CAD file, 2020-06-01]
stl/v1.1/housing_rev1.0-3.0/housing_with_fuse.stl
68.0 x 43.6 x 33.0

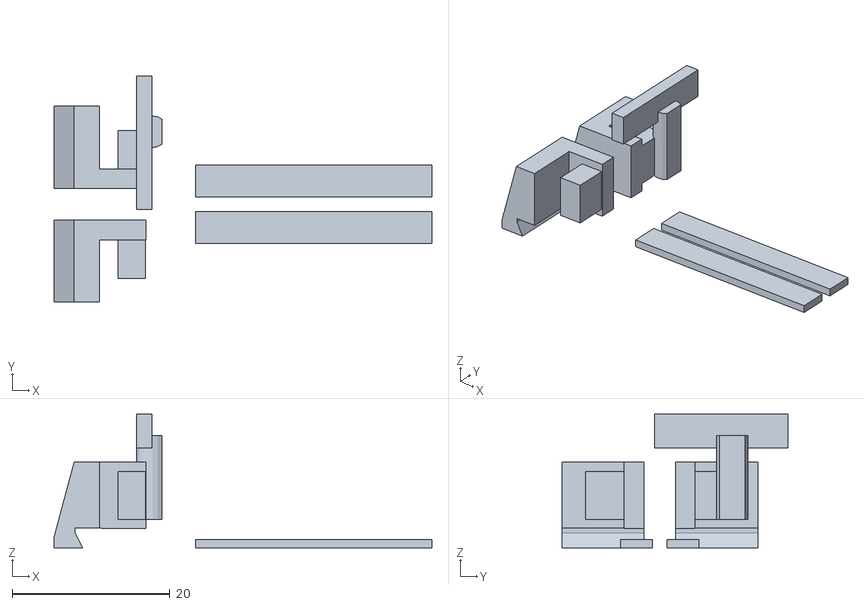
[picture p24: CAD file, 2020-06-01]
stl/v1.1/housing_with_power_monitor_rev1.0-1.3/housing_with_fuse_support.stl
48.0 x 28.7 x 17.0

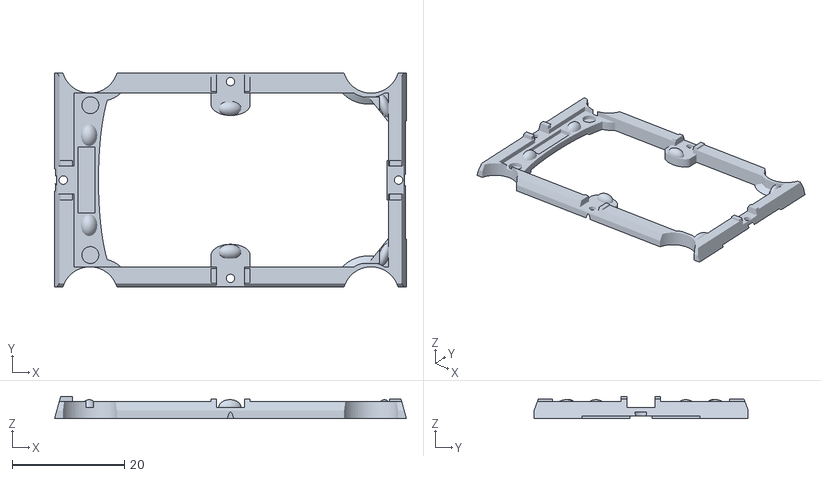
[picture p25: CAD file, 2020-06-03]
stl/v1.1/pcb_holder.stl
62.6 x 38.0 x 4.00

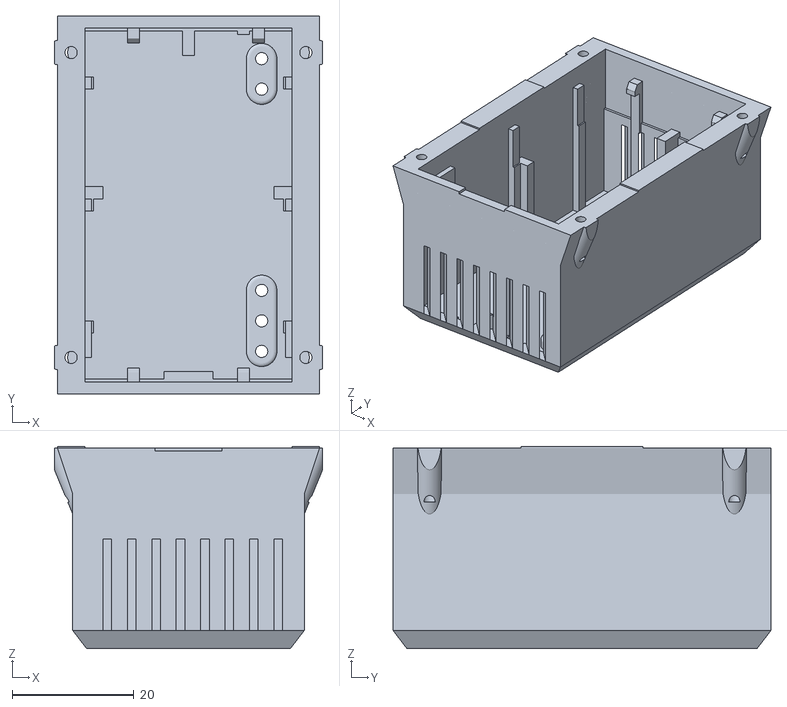
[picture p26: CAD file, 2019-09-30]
stl/housing/housing.stl
44.0 x 62.0 x 33.2

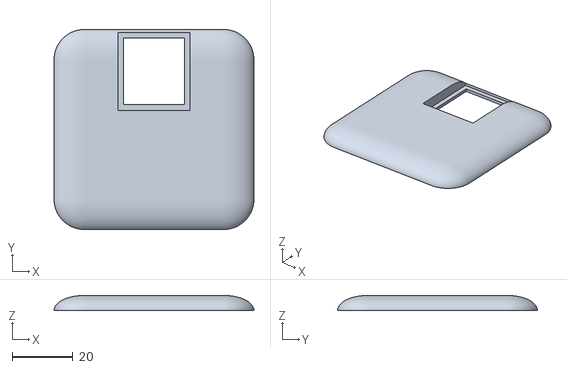
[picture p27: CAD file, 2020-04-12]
stl/housing/plugin/cover.stl
66.0 x 66.0 x 5.00

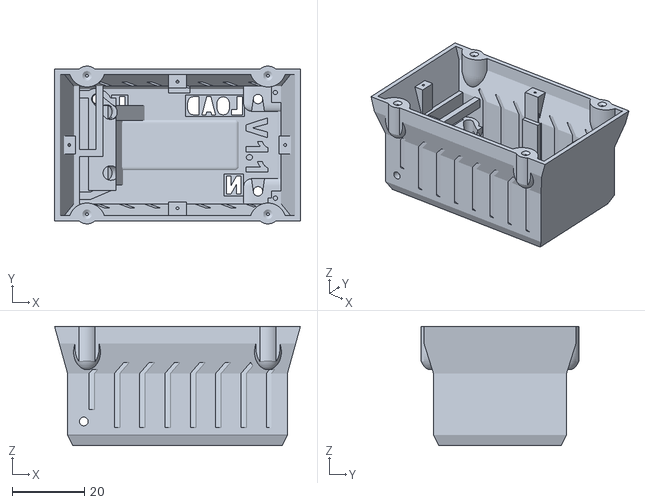
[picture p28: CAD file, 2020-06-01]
stl/v1.1/housing_with_power_monitor_rev1.0-1.3/housing_with_fuse.stl
68.0 x 43.6 x 33.0

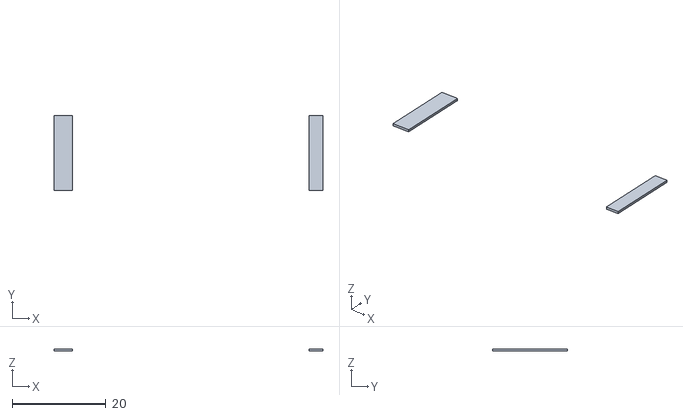
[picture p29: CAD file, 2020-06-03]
stl/v1.1/pcb_holder_support.stl
57.5 x 16.0 x 0.5

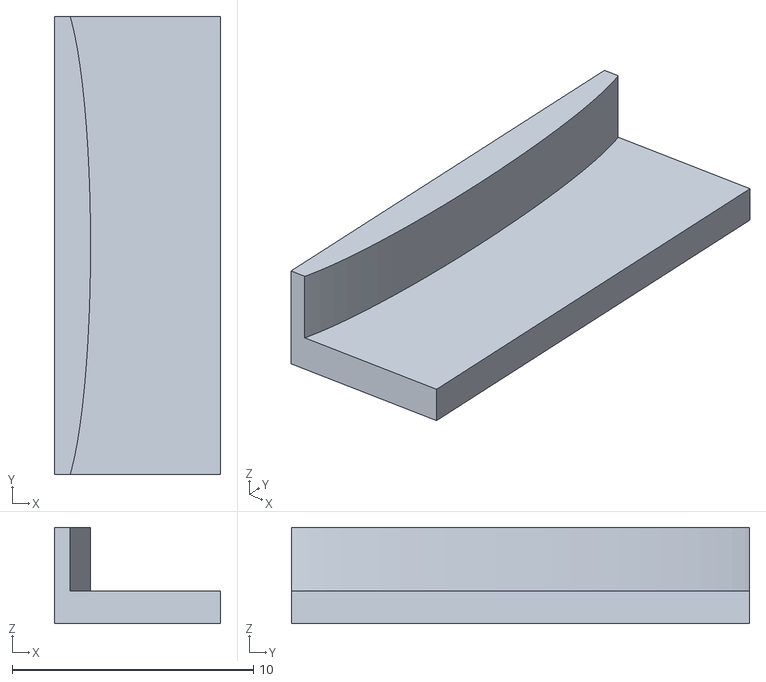
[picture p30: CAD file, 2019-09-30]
stl/housing/rocker_holder.stl
6.89 x 19.0 x 4.00

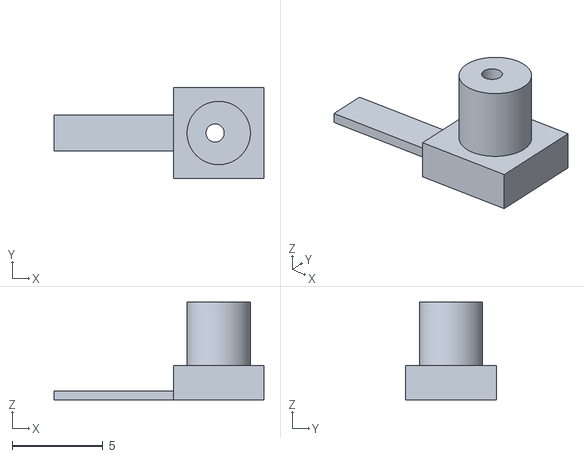
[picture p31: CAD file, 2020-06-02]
stl/v1.1/hole_inlay_0.2mm_moved.stl
11.6 x 5.00 x 5.40

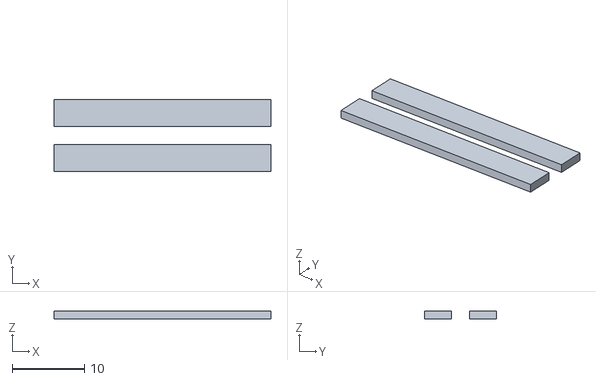
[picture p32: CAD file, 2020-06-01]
stl/v1.1/housing_rev1.0-3.0/housing_support.stl
30.0 x 10.0 x 1.10

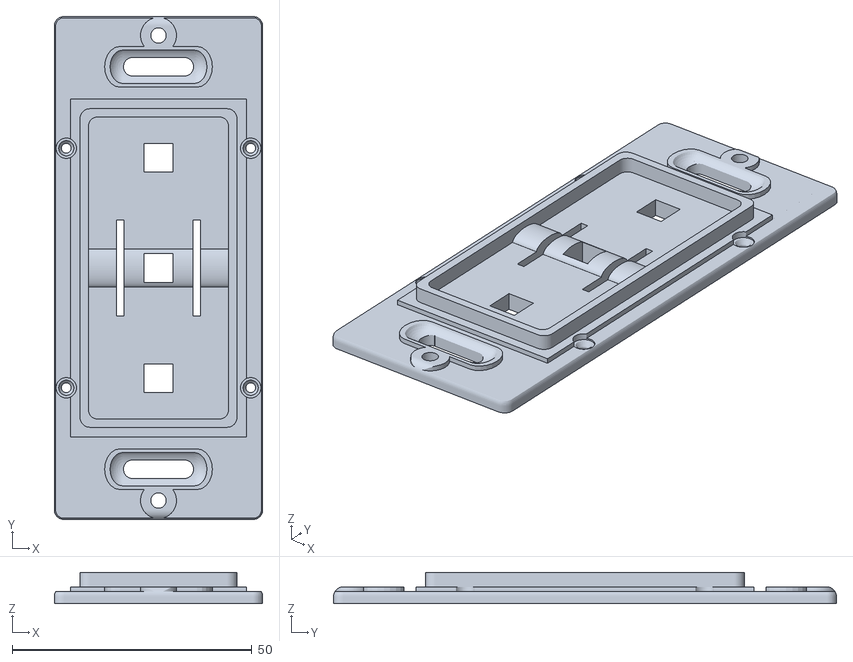
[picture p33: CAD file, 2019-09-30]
stl/housing/plate.stl
43.5 x 105.0 x 6.55

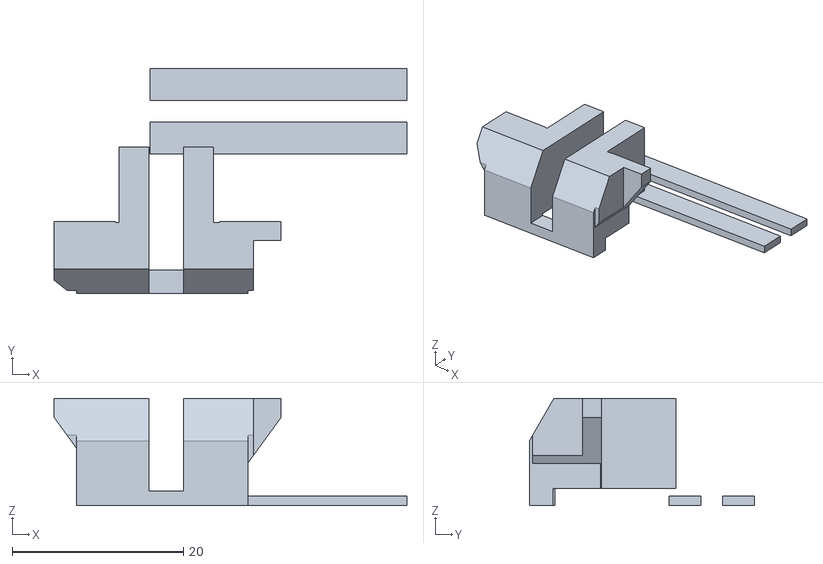
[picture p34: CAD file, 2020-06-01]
stl/v1.1/housing_rev1.0-3.0/housing_with_fuse_support.stl
41.2 x 26.3 x 12.5

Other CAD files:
stl/v1.1/housing_rev1.0-3.0/housing.stl
stl/v1.1/housing_with_power_monitor_rev1.0-1.3/housing.stl
stl/v1.1/hole_inlay_0.05mm_moved.stl
stl/v1.1/housing_with_power_monitor_rev1.0-1.3/housing_support.stl
stl/housing/rocker.stl
stl/v1.1/fuse_holder.stl
stl/v1.1/hole_inlay_0.1mm_moved.stl
stl/v1.1/letters_black.stl
stl/v1.1/letters_white.stl
stl/v1.1/plate/plate_bigscrews.stl
stl/v1.1/plate/plate_bigscrews_support.stl
stl/v1.1/plate/plate_smallscrews.stl
stl/v1.1/plate/plate_smallscrews_support.stl

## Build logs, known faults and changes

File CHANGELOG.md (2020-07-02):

# Changelog

## 3.0.0

- Rewritten timer code in C++
- Added cubic interpolation for dimmer level curves per channel
- Support for frequencies between 45 and 65Hz, auto detection
- Continues measurement of the AC frequency and adjustments
- Filtering of invalid ZC signals (i.e. caused by transients)
- Additional settings for dimmer info and some fixes
- Reduced max. temperature to 80°C
- Removed linear correction
- Changes in I2C protcol and register memory (not compatible with 2.x)
- Inline assembler code generation to improve switching times
- Improved EEPROM wear leveling, data integry checks and redundancy ([ArduinoEEPROM](TODO))
- Fixed storing channel levels while fading
- GUI configuration tool

## 2.1.4

- Added DIMMER_ZC_INTERRUPT to specify rising or falling interrupt triggering
- Removed DIMMER_COMMAND_RESET since it was not working with several versions of the bootloader

## 2.1.3

- Fixed bug in EEPROM wear leveling and invalid CRC after cycling
- Added output of EEPROM read/write status to serial port

## 2.1.2

- Fixed 32bit overflow in timer that caused the zero crossing detection to malfunction
- Added +REM=BOOT message in setup()

## 2.1.1

- Changed max. temperature to 90°C which is the maximum operation temperature allowed for dimmers (195F)
- Added filter to skip all ZC interrupts above 90Hz (@60Hz mains)
- Added error counter for high/low frequency and zero crossing misfire
- Added debugging code to send zero crossing interrupt timings to serial port (ZC_MAX_TIMINGS)
- Fixed wrong NTC PIN at dimmer info

## 2.1.0

- Added version to register memory (DIMMER_REGISTER_VERSION)
- Added print dimmer info command (DIMMER_COMMAND_PRINT_INFO)
- Added command force temperature check (DIMMER_COMMAND_FORCE_TEMP_CHECK)
- Added structure dimmer_metrics_t for DIMMER_RESPONSE_METRICS_REPORT
- Added CRC16 to EEPROM configuration
- Added event that indicates that the EEPROM has been written (DIMMER_RESPONSE_EEPROM_WRITTEN)
- Added print metrics on serial port (DIMMER_COMMAND_PRINT_METRICS)
- Added offset for internal temperature sensor and ntc (DIMMER_REGISTER_xxx_TEMP_OFS, int8 * 0.25 °C, ~ +-32°C)
- Added warning if the AC frequency is below 75% or above 120% (DIMMER_RESPONSE_FREQUENCY_WARNING)
- Added undocumented commands for testing and calibration (0x80-0x91, i2c_slave.cpp)
- Added MCU detection for adjusting internal temperature sensor
- DIMMER_COMMAND_READ_NTC, DIMMER_COMMAND_READ_INT_TEMP and DIMMER_COMMAND_READ_AC_FREQUENCY return NaN if not available, DIMMER_COMMAND_READ_VCC 0
- Fixed outdated debug code
- Fixed issue with reading ADC values and delay() inside the I2C interrupt callback
- Fixed empty configuration structure after reset without calling _write_config()
- Fixed int overflow for temp_check_interval > 32
- Fixed pin mode for NTC
- Fixed fading with short time intervals and float not having enough precision for a sinle step
- Changed default values for ZC crossing delay and other timings to match my dimmer design
- Changed DIMMER_TEMPERATURE_REPORT to DIMMER_RESPONSE_METRICS_REPORT

## 2.0.2

- Configurable timing parameters for the MOSFET
- Added documentation for timings to dimmer.h
- Display compile settings and values during start up (HIDE_DIMMER_INFO)
- Added AC frequency measurement (FREQUENCY_TEST_DURATION)
- Enabled printf float formatting and removed PrintEx library
- Added event to indicate when a fading operation has been completed (HAVE_FADE_COMPLETION_EVENT)
- Fixed an issue with floats and rounding when using fading

## 2.0.1

- Changed default I2C address to 0x17/0x18
- Increased delay when reading internal temperature and VCC
- Added macros for thermistor temperature calculation
- Changed macro names to match pattern, additional macros to enable/disable reading VCC, NTC, internal temp. sensor

## 2.0.0

- Added [I2C slave protocol](docs/protocol.md)
- The serial protocol was replaced by [I2C over UART emulation](https://github.com/sascha432/i2c_uart_bridge)
- Added example how to control the dimmer via I2C and UART
- Removed SLIM version
- Auto select prescaler bits for DIMMER_TIMER2_PRESCALER
- Changes for Platform IO 4.0

## 1.0.9

- Added some extra ticks if timer interrupts are close to avoid skipping one
- Improved the timing of the zero crossing interrupt using timer2
- Added min. "on" time

## 1.0.8

- Added VCC to dimmer info and temperature report (INTERNAL_VREF_1_1V might need some adjustments to be precise)
- Added CPU Frequency to dimmer info
- Support for ATMEGA Mini Pro 3.3V @ 8MHz
- Set default prescaler to 8 increasing dimming levels to 16666 for 16MHz and 8333 for 8MHz
- Respond to invalid commands with error
- Changed part of the fade response from "to=" to "lvl="

## 1.0.7

- Support for the internal temperature sensor of the ATMEGA

## 1.0.6

- EEPROM wear leveling to increase writes ((EEPROM size - 8 byte) / size of configuration) = 50, which should be ~5 million writes

## 1.0.5

- EEPROM write delay to reduce writes
- Added prefix "~$" for commands

## 1.0.4

- Slim version with less than 7.5kb for ATMEGA88. No EEPROM support and different serial protocol

## 1.0.3

- Serial command to change configuration
- Store configuration in EEPROM

## 1.0.2

- NTC with configurable over temperature shutdown
- Store last levels in EEPROM and restore when power is turned on

## 1.0.1

- Added support for multiple channels to the dimmer library
- Added debug code
- Increased dimming levels to 32767 (DIMMER_MAX_LEVEL)

## 1.0.0

- Initial version

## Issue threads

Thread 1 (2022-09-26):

Unable to build on linux host

Cyril-Roques, 2022-09-26:
Hello,

I have tried to compile your project on a linux box (debian testing with visual studio code 1.68.1 and platformio 6.1.4) this do not work. the compilation is stuck calling python scripts from extra_script.py. I have changed shell=True to shell=False and the compilation is going fine now.

I don't have a windows to check this, so I don't have made a pull request.

This is the diff:
```diff
--- a/scripts/extra_script.py
+++ b/scripts/extra_script.py
@@ -63,7 +63,7 @@ def disassemble(source, target, env):
     if verbose_flag:
         print(' '.join(args))

-    return_code = subprocess.run(args, shell=True).returncode
+    return_code = subprocess.run(args, shell=False).returncode
     if return_code!=0:
         error('Failed to disassemble binary: exit code %u: %s' % (return_code, ' '.join(args)))

@@ -77,7 +77,7 @@ def read_def(source, target, env):
     project_dir = path.realpath(env.subst("$PROJECT_DIR"))
     script = path.realpath(path.join(project_dir, './scripts/read_def.py'))
     args = [ python, script ]
-    return_code = subprocess.run(args, shell=True).returncode
+    return_code = subprocess.run(args, shell=False).returncode
     if return_code!=0:
         error('Failed to run script: exit code %u: %s' % (return_code, ' '.join(args)))

@@ -133,7 +133,7 @@ def update_dimmer_inline_asm(source, target, env):
         env.Exit(1)

     args = [ python, script, '--output', output, '--zc-pin', zc_pin,  '--pins' ] + pins
-    return_code = subprocess.run(args, shell=True).returncode
+    return_code = subprocess.run(args, shell=False).returncode
     if return_code!=0:
         error('Failed to run script: exit code %u: %s' % (return_code, ' '.join(args)))

```

sascha432, 2022-11-22:
Thanks, I recently switched to linux (compiling is also twice as fast as on windows, at least for the ESP8266/32) and saw that issue as well. I did not try on OSX yet if you need true or false, but I guess it is like linux.

Closed 2022-11-22.

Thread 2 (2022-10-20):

Question, comments on hardware

Findus76, 2022-10-20:
Question
I am in the process of designing a dimmer, both hardware and software. Your project is clearly interesting as a starting point.
- Having ESP32. Can the ATmegan be skipped, or is it needed for the realtime feature?
- Which schematic versions do you recommend to start from, for both zirocrossing and transistor control?

sascha432, 2022-11-22:
I would not recommend to use the ESP32, since it is not 100% stable and you would need a lot experience in RTOS to dedicate the second core to the dimmer for precise timings/mutex locks etc. And it will probably require some assembler code as well, I do not think the framework is able to handle anything in the micro second range. The single core is not suitable at all.

In case you use my zero crossing, its highly recommended to use my code as well since it has filters and predictive zero crossing detection to avoid any misfires that are not filtered by the hardware. AC turning on, or vacuum cleaner.. might lead to flickering lights. Due to the low amount of power it requires its also pretty sensitive without software filtering.

https://oshwlab.com/sascha23095123423/iot_1ch_dimmer_copy_copy_copy
or
https://oshwlab.com/sascha23095123423/iot-4-channel-dimmer-with-pm

You can copy the parts you need for your version of the dimmer. But using the AVR you got it all and the code is stable (2.2.2).
There is a lot ways to control the mains power stage (mosfets, mosfets with a driver, mosfets controlled by the opto coupler directly, triacs or even simple transistors with diodes for low power)

Closed 2022-11-22.

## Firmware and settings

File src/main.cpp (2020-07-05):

/**
 * Author: sascha_lammers@gmx.de
 */

// 1-8 Channel Dimmer with I2C interface

// 29484, 29280, 29310, 29294, 29212, 29170, 29108, 29004, 29102, 28918, 29074, 29044, 29086, 29248, 29084, 28998, 29000, 28916, 28136, 27962, 27586, 27584, 27536

#include <Arduino.h>
#include "i2c_slave.h"
#include "sensors.h"
#include "helpers.h"
#include "cubic_interpolation.h"
#include <EEPROM.h>

unsigned long update_metrics_timer = 0;
unsigned long send_metrics_timer = 0;
#if HAVE_PRINT_METRICS
bool print_metrics_enabled = false;
#endif

void rem()
{
#if SERIAL_I2C_BRDIGE
    Serial.print(F("+REM="));
#endif
}

void display_dimmer_info()
{
    rem();
    Serial.println(F("MOSFET Dimmer " DIMMER_VERSION " " __DATE__ " " __TIME__ " " DIMMER_INFO));

    rem();
    MCUInfo_t mcu;
    get_mcu_type(mcu);

    Serial.printf_P(PSTR("sig=%02x-%02x-%02x,fuses=l:%02x,h:%02x,e:%02x"), mcu.sig[0], mcu.sig[1], mcu.sig[2], mcu.fuses[0], mcu.fuses[1], mcu.fuses[2]);
    if (mcu.name) {
        Serial.printf_P(PSTR(",MCU=%S"), mcu.name);
    }
    Serial.printf_P(PSTR("@%uMhz\n"), (unsigned)(F_CPU / 1000000UL));

    rem();
    Serial.print(F("options="));
    Serial.printf_P(PSTR("Factory=%u,"), register_mem.data.cfg.bits.factory_settings);
#if HAVE_NTC
    // Serial.printf_P(PSTR("NTC=A%u,"), NTC_PIN - A0);
    Serial.print(F("NTC=" _STRINGIFY(NTC_PIN) ","));
#endif
#if HAVE_READ_INT_TEMP && HAVE_READ_VCC
    Serial.print(F("IntTemp,VCC,"));
#else
#if HAVE_READ_INT_TEMP
    Serial.print(F("IntTemp,"));
#endif
#if HAVE_READ_VCC
    Serial.print(F("VCC,"));
#endif
#endif
#if DIMMER_CUBIC_INTERPOLATION
    Serial.print(F("CubicInt,"));
#endif
#if SERIAL_I2C_BRDIGE
    Serial.print(F("Pr=UART,"));
#else
    Serial.print(F("Pr=I2C,"));
#endif
#if HAVE_FADE_COMPLETION_EVENT
    Serial.print(F("CE=1,"));
#endif
    Serial.printf_P(PSTR("Addr=%02x,Pre=" _STRINGIFY(DIMMER_TIMER1_PRESCALER) ",Ticks=%.1fus,MaxLvls=" _STRINGIFY(DIMMER_MAX_LEVELS) ",GPIO/lvl="), DIMMER_I2C_ADDRESS,1 / DIMMER_T1_TICKS_PER_US);
    FOR_CHANNELS(i) {
        Serial.print((int)kDimmerPins[i]);
        Serial.print('/');
        Serial.print(dimmer_level(i));
        if (i < Dimmer::kMaxChannels - 1) {
            Serial.print(',');
        }
    }
    Serial.println();

    rem();
    Serial.printf_P(PSTR("values=Restore=%u,Frq=%.3f,Ref11=%.4f,"), register_mem.data.cfg.bits.restore_level, dimmer.getFrequency(), register_mem.data.cfg.vref11);
#if HAVE_NTC
    Serial.printf_P(PSTR("NTC=%.2f/%+.1fC,"), Sensors::readTemperature(), register_mem.data.cfg.temperature_offset / DIMMER_TEMP_OFFSET_DIVIDER);
#endif
#if HAVE_READ_INT_TEMP
    Serial.printf_P(PSTR("IntTemp=%.2f/%+.1fC,"), Sensors::readTemperature2(), register_mem.data.cfg.temperature2_offset / DIMMER_TEMP_OFFSET_DIVIDER);
#endif
    Serial.printf_P(PSTR("MaxTmp=%u,Metrics=%us,"), register_mem.data.cfg.max_temperature, register_mem.data.cfg.metrics_report_interval);
#if HAVE_READ_VCC
    Serial.printf_P(PSTR("VCC=%.3f,"), Sensors::readVCC());
#endif
#if DIMMER_CUBIC_INTERPOLATION
    Serial.print(F("CubInt="));
    cubicInterpolation.printState();
#endif
    Serial.printf_P(PSTR("MinOn/Off=%u/%.1fus,%u/%.1fus,ZC=%d/%.1fus\n"),
        register_mem.data.cfg.min_on_ticks,
        DIMMER_T1_TICKS_TO_US_FLOAT(register_mem.data.cfg.min_on_ticks),
        register_mem.data.cfg.min_off_ticks,
        DIMMER_T1_TICKS_TO_US_FLOAT(register_mem.data.cfg.min_off_ticks),
        register_mem.data.cfg.zc_offset_ticks,
        DIMMER_T1_TICKS_TO_US_FLOAT(register_mem.data.cfg.zc_offset_ticks)
    );
    rem();
    Serial.printf_P(PSTR("errors=ZCmisfire=%u,temp=%u\n"),
        register_mem.data.errors.zc_misfire,
        register_mem.data.errors.temperature
    );
}

void setup()
{
    Serial.begin(DEFAULT_BAUD_RATE);
    #if SERIAL_I2C_BRDIGE && DEBUG
    _debug_level = 9;
    #endif

    Serial.println(F("+REM=BOOT"));

#if HAVE_NTC
    pinMode(NTC_PIN, INPUT);
#endif

    regMem.begin();

    ConfigStorage::Settings settings;
    config.read(settings);
    dimmer.begin();

    delay(100);
    Serial.println(F("+REM=Measuring frequency"));
    if (dimmer.measure(1000)) {
        // dimmer.enable();
    }
    else {
        Serial.println(F("+REM=timeout"));
    }

    // copy settings and restore channel level if enabled
    settings.copyFrom();

    ATOMIC_BLOCK(ATOMIC_FORCEON) {//TODO debug remove
        dimmer.setLevel(0, 2000);
        dimmer.setLevel(1, 2300);
        dimmer.setLevel(2, 7301);
        dimmer.setLevel(3, 2301);
    }

    display_dimmer_info();
}

void loop()
{
#if DIMMER_SIGNAL_GENERATOR_JITTER
    static unsigned long signalTimer = 0;
    if (millis() >= signalTimer) {
        signalTimer = millis() + 5000;
        if (OCR2A > 140) {
            // while(TCNT2!=OCR2A-1) ;
            OCR2A--;
        }
        else {
            OCR2A = 150;
        }
    }
#endif

    dimmer.sendFadingCompletedEvents();

    cli();
    if (millis() > config._eepromWriteTimer) {
        config._eepromWriteTimer = ConfigStorage::kEEPROMTimerDisabled;
        sei();
        config.writeSettings();
    }
    sei();

    // updating metrics takes 82ms (96ms with print_metrics_enabled)
    if (millis() >= update_metrics_timer) {
#define DEBUG_MEAS_METRICS_TIME 0
#if DEBUG_MEAS_METRICS_TIME
        auto start = micros();
#endif
        update_metrics_timer = millis() + DIMMER_UPDATE_METRICS_INTERVAL;

        register_mem_metrics_t tmp = { dimmer.getFrequency(), Sensors::readTemperature(), Sensors::readTemperature2(), Sensors::readVCCmV() };
        int16_t current_temp = max((int16_t)tmp.temperature, (int16_t)tmp.temperature2); // pick highest temperature

        ATOMIC_BLOCK(ATOMIC_FORCEON) {
            register_mem.data.metrics = tmp;
        }

        if (register_mem.data.cfg.max_temperature && current_temp > (int16_t)register_mem.data.cfg.max_temperature) {
            // max. temperature exceeded, turn all channels off
            dimmer.setFade(-1, DIMMER_FADE_FROM_CURRENT_LEVEL, 0, 10);
            // store alert and save
            register_mem.data.errors.temperature++;
            config.writeSettings();

            // send temperature alert
            Wire.beginTransmission(DIMMER_I2C_MASTER_ADDRESS);
            Wire.write(DIMMER_MASTER_COMMAND_TEMPERATURE_ALERT);
            Wire.write(current_temp);
            Wire.write(register_mem.data.cfg.max_temperature);
            Wire.endTransmission();
        }

        if (register_mem.data.cfg.bits.report_metrics) {
            if (millis() >= send_metrics_timer) {
                // no check if metrics_report_interval is zero needed since it is limited to DIMMER_UPDATE_METRICS_INTERVAL
                send_metrics_timer = millis() + (register_mem.data.cfg.metrics_report_interval * 1000UL);

                // send metrics
                Wire.beginTransmission(DIMMER_I2C_MASTER_ADDRESS);
                Wire.write(DIMMER_MASTER_COMMAND_METRICS_REPORT);
                Wire_write(register_mem.data.metrics);
                Wire.endTransmission();
            }
        }

#if DEBUG_MEAS_METRICS_TIME
        auto stop1 = micros();
#endif

#if HAVE_PRINT_METRICS
        if (print_metrics_enabled) {
            Serial.printf_P(PSTR("+REM=ram=%u,stack=%u\n"), freeMemory(), stackAvailable());
            Serial.printf_P(PSTR("+REM=freq=%.2fHz/%u,temp=%.2f,temp2=%.2f,VCC=%u,lvl=%u"),
                tmp.frequency,
                dimmer.getHalfWaveTicks(),
                tmp.temperature,
                tmp.temperature2,
                tmp.vcc,
                register_mem.data.channels.level[0]
            );
#if DIMMER_CHANNELS>1
            for(dimmer_channel_id_t i = 1; i < Dimmer::kMaxChannels; i++) {
                Serial.print(',');
                Serial.print(register_mem.data.channels.level[i]);
            }
#endif
            Serial.println();
            Serial.flush();
        }
#endif

#if DEBUG_MEAS_METRICS_TIME
        auto stop2 = micros();
        Serial.printf_P(PSTR("update metrics %lu %lu\n"), stop1 - start, stop2 - start);
#endif

    }
}

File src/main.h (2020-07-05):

/**
 * Author: sascha_lammers@gmx.de
 */

#pragma once

#include <util/atomic.h>
#include "dimmer.h"
#include "i2c_slave.h"
#if SERIAL_I2C_BRDIGE
#include "SerialTwoWire.h"
#else
#include <Wire.h>
#endif

#if DIMMER_CHANNELS > 8
#error A maximum of 8 channels is supported
#endif

#ifndef SERIAL_I2C_BRDIGE
#define SERIAL_I2C_BRDIGE                       0
#endif

#ifndef DEFAULT_BAUD_RATE
#define DEFAULT_BAUD_RATE                       115200
#endif

#ifndef HAVE_NTC
#define HAVE_NTC                                1
#endif

#ifndef HAVE_READ_VCC
#define HAVE_READ_VCC                           1
#endif

#ifndef HAVE_READ_INT_TEMP
#define HAVE_READ_INT_TEMP                      1
#endif

// NTC pin
#ifndef NTC_PIN
#define NTC_PIN                                 A1
#endif

// beta coefficient
#ifndef NTC_BETA_COEFF
#define NTC_BETA_COEFF                          3950
#endif
// resistor in series with the NTC
#ifndef NTC_SERIES_RESISTANCE
#define NTC_SERIES_RESISTANCE                   3300
#endif
// ntc resistance @ 25°C
#ifndef NTC_NOMINAL_RESISTANCE
#define NTC_NOMINAL_RESISTANCE                  10000
#endif

#ifndef NTC_NOMINAL_TEMP
#define NTC_NOMINAL_TEMP                        25
#endif

#ifndef HAVE_PRINT_METRICS
#define HAVE_PRINT_METRICS                      1
#endif

#ifndef HAVE_CUBIC_INT_PRINT_TABLE
#define HAVE_CUBIC_INT_PRINT_TABLE              0
#endif

#ifndef HAVE_CUBIC_INT_GET_TABLE
#define HAVE_CUBIC_INT_GET_TABLE                0
#endif

#ifndef HAVE_CUBIC_INT_TEST_PERFORMANCE
#define HAVE_CUBIC_INT_TEST_PERFORMANCE         0
#endif

constexpr uint8_t kRegisterMemInfoOptionsBitValue = 0
#if DIMMER_CUBIC_INTERPOLATION
    |DIMMER_OPTIONS_INFO_HAS_CUBIC_INTERPOLATION
#endif
#if HAVE_NTC
    |DIMMER_OPTIONS_INFO_HAS_TEMPERATURE
#endif
#if HAVE_READ_INT_TEMP
    |DIMMER_OPTIONS_INFO_HAS_TEMPERATURE2
#endif
#if HAVE_READ_VCC
    |DIMMER_OPTIONS_INFO_HAS_VCC
#endif
#if HAVE_FADE_COMPLETION_EVENT
    |DIMMER_OPTIONS_INFO_HAS_FADING_COMPLETED_EVENT
#endif
;

#if HAVE_READ_INT_TEMP
extern bool is_Atmega328PB;
#define setAtmega328PB(value) is_Atmega328PB = value;
#else
#define setAtmega328PB(value) ;
#endif

extern unsigned long update_metrics_timer;

#if HAVE_PRINT_METRICS
extern bool print_metrics_enabled;
#endif

template<class T>
uint8_t Wire_read(T &data) {
    return Wire.readBytes(reinterpret_cast<uint8_t *>(&data), sizeof(data));
}

template<class T>
uint8_t Wire_write(T &data) {
    return Wire.write(reinterpret_cast<const uint8_t *>(&data), sizeof(data));
}

void rem();
void display_dimmer_info();

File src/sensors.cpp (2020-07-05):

/**
 * Author: sascha_lammers@gmx.de
 */

#include "main.h"
#include "sensors.h"

#if HAVE_NTC

static uint16_t read_ntc_value()
{
    uint16_t value = analogRead(NTC_PIN);
    delay(1);
    return (value + analogRead(NTC_PIN)) / 2;
}

static float convert_to_celsius(uint16_t value)
{
    float steinhart;
    steinhart = (1023 / (float)value) - 1;
    steinhart *= NTC_SERIES_RESISTANCE;
    steinhart /= NTC_NOMINAL_RESISTANCE;
    steinhart = log(steinhart);
    steinhart /= NTC_BETA_COEFF;
    steinhart += 1.0 / (NTC_NOMINAL_TEMP + 273.15);
    steinhart = 1.0 / steinhart;
    steinhart -= 273.15;
    return steinhart;
}

#endif

uint16_t Sensors::readVCCmV()
{
    return readVCC() * 1000;
}

float Sensors::readVCC()
{
#if HAVE_READ_VCC

    ADMUX = _BV(REFS0) | _BV(MUX3) | _BV(MUX2) | _BV(MUX1);
    delay(40);
    ADCSRA |= _BV(ADSC);
    while (bit_is_set(ADCSRA, ADSC)) ;
    return 1024.0 * register_mem.data.cfg.vref11 / (float)ADCW;

#else

    return 0;

#endif
}

float Sensors::readTemperature()
{
#ifdef FAKE_NTC_VALUE

    return FAKE_NTC_VALUE;

#elif HAVE_NTC

    return convert_to_celsius(read_ntc_value()) + (register_mem.data.cfg.temperature_offset / DIMMER_TEMP_OFFSET_DIVIDER);

#else

    return NAN;

#endif

}

#if HAVE_READ_INT_TEMP
bool is_Atmega328PB = false; // runtime variable since the bootloader reports Atmega328P
#endif

float Sensors::readTemperature2()
{
#if HAVE_READ_INT_TEMP

    // https://playground.arduino.cc/Main/InternalTemperatureSensor/

    ADMUX = (_BV(REFS1) | _BV(REFS0) | _BV(MUX3));
    ADCSRA |= _BV(ADEN);
    delay(40); // 20 was not enough. It takes quite a while when switching from reading VCC to temp.
    ADCSRA |= _BV(ADSC);
    while (bit_is_set(ADCSRA, ADSC)) ;
    // TODO verify calculation, it is way off for a couple of chips
    return ((ADCW - (is_Atmega328PB ? 247.0f : 324.31f)) / 1.22f) + (register_mem.data.cfg.temperature2_offset / DIMMER_TEMP_OFFSET_DIVIDER);

#else

    return NAN;

#endif
}

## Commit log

2019-06-16 schematic of the development board and a picture
2019-07-04 Images/schematics moved
2019-09-30 3D model
    [housing.stl, insulation-spacer.stl, plate.stl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]
2019-10-30 Calibration info
2019-12-18 Power monitoring
2020-04-12 STL files for plugin dimmer
    [cover.stl, housing.stl]
2020-06-01 added info for calibration
2020-06-01 added version v1.1 of the STL files
    [fuse_holder.stl, housing.stl, housing_support.stl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]
2020-06-01 Dimensions updated
    [housing.stl, housing_with_fuse.stl, pcb_holder.stl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]
2020-06-02 STL files
    [hole_inlay_0.05mm_moved.stl, hole_inlay_0.1mm_moved.stl, hole_inlay_0.2mm_moved.stl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]
2020-06-03 STL updates
    [pcb_holder.stl, pcb_holder_support.stl, plate_bigscrews.stl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]
2020-06-18 inline assembler optimization
2020-06-18 inline asm and compare A miss bug fixed
    [dimmer.cpp]
2020-06-18 zero crossing delay testing
    [bottom.stl, clip_4.1mm.stl, clip_4.3mm.stl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]
2020-06-18 Revert "zero crossing delay testing"
    This reverts commit 3cc6d1ac9b1420bd1f68ddad1fbbd710f4bcc22d.
    [bottom.stl, clip_4.1mm.stl, clip_4.3mm.stl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]
2020-07-05 bugfixes and improved cubic interpolation
    [cubic_interpolation.cpp, dimmer.cpp, dimmer.h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]
